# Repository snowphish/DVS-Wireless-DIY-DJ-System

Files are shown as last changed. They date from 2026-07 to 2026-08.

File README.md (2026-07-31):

# Wireless DIY DVS

## Lineage and AI authorship disclosure

This is my own spin on the original project from
[FelipeAlme/DVS-Wireless-DIY-DJ-System](https://github.com/FelipeAlme/DVS-Wireless-DIY-DJ-System),
which established the original transmitter and receiver system. This fork
includes some added functionality like unified receiver control, spin
calibration, automatic pairing, failover, telemetry, the Windows Manager, and
web flashing.

**All programming in this fork has been done by AI.** The project owner has
provided the requirements, hardware design decisions, physical builds, testing,
diagnosis feedback, and final approval, while AI systems generated and modified
the firmware, desktop application, web flasher, build tooling, and documentation.

Wireless DIY DVS turns two ordinary turntables into a two-deck digital vinyl
control system without needles or timecode records. Battery-powered ESP32-C3
gyro pucks measure platter movement over ESP-NOW, while one ESP32-S3 receiver
generates line-level Serato CV02 timecode or a Traktor-compatible quadrature
carrier signal for both decks.

> **[Flash the receiver and pucks in Chrome or Edge](https://snowphish.github.io/DVS-Wireless-DIY-DJ-System/)**

The package also includes a self-contained Windows x64 manager for monitoring,
pairing, calibration, deck swapping, and receiver settings over USB.

## System overview

```text
Turntable 1 + gyro puck --\                         /--> DAC A --> audio interface
                            ESP-NOW --> S3 receiver
Turntable 2 + gyro puck --/                         \--> DAC B --> audio interface
                                         |
                                         +--> USB --> DVS Manager for Windows
```

One receiver handles both decks. Both pucks run the same firmware for their
sensor type; deck 1 and deck 2 are assigned automatically during pairing and
can be swapped later from DVS Manager.

## Highlights

- Full Serato CV02 output and carrier-only Traktor output from one unified
  receiver build.
- Two simultaneous decks over low-latency ESP-NOW on channel 11.
- MPU6050 and BMI160/BMI120 transmitter variants.
- Automatic MAC-based pairing and reconnect to the puck's previous deck.
- One-time platter-speed calibration stored independently by each puck.
- Hold-last-stable-RPM failover if a wireless link drops.
- Live battery voltage, RPM, 7-second signal/loss averages, and packet age.
- USB configuration with automatic COM-port discovery and reconnection.
- Adjustable output gain, base speed, LED brightness, battery threshold, and
  pairing window, including an option to suppress low-battery LED flashing.
- Browser-based flashing with no Arduino installation required.

## Quick start

1. Open the **[web flasher](https://snowphish.github.io/DVS-Wireless-DIY-DJ-System/)**
   in desktop Chrome or Edge.
2. Flash **Unified receiver** to the ESP32-S3 receiver.
3. Flash the transmitter build matching each puck's gyro:
   - `MPU6050` for MPU6050 pucks.
   - `BMI160 / BMI120` for either Bosch chip ID `0xD1` or `0xD3`.
4. Power the receiver first, then switch on the two pucks one at a time. The
   first new puck becomes deck 1 and the second becomes deck 2.
5. Connect the receiver's native USB data port to Windows and run
   [`Windows_Manager/DVSManager.exe`](Windows_Manager/DVSManager.exe).
6. Select Serato CV02 or Traktor carrier in **Settings**, choose the platter
   speed in **Quick controls**, and calibrate with the platters settled at 0%
   pitch.
7. Connect both PCM5102A outputs to the audio interface's **line inputs**, set
   up the corresponding input mode in the DJ software, and use **Relative
   mode**.

### Important Traktor limitation

The current Traktor mode outputs only the bare quadrature carrier used for
speed and direction tracking. It does **not** generate the complete Traktor
Scratch MK2 position/authenticity bitstream, so Traktor will not detect it as
genuine timecode for now.

Use **Relative mode** and disable Traktor's timecode error messages/warnings.
With those errors disabled, Traktor can follow platter speed and direction from
the carrier, but genuine-timecode detection and absolute position are not
available. Serato mode is unaffected and continues to output full CV02
timecode.

The Windows executable is not code-signed, so SmartScreen may show an
unrecognized-app warning. Verify it against [`SHA256SUMS.txt`](SHA256SUMS.txt)
before choosing **More info > Run anyway**.

## Pairing and deck assignment

- The receiver opens its pairing window at boot.
- The first unassigned puck becomes deck 1; the second becomes deck 2.
- A previously paired puck that reconnects reclaims its own deck.
- **Open pairing** in DVS Manager allows a new puck to claim a free deck.
- **Swap decks** exchanges the two assignments without reflashing either puck.
- Holding the receiver's GPIO 4 pairing button for about 1.5 seconds clears
  both assignments and reopens pairing.

## Calibration

Power each puck on while its platter is stopped so boot-time gyro zeroing is
valid. For the one-time speed calibration:

1. Set both turntables to 33 1/3 or 45 RPM with pitch at exactly 0%.
2. Let the platters settle completely.
3. Select the same base speed under **Quick controls**.
4. Click **Calibrate pucks at selected speed**.
5. Do not touch either platter during the roughly 10-second sample.

The learned gyro scale is saved in each puck. Normal power-on zeroing still
happens every time because gyro bias changes with temperature.

## DVS Manager

`DVSManager.exe` is a portable, self-contained .NET 8 application for 64-bit
Windows. No installer or separate .NET runtime is required. It automatically
finds the receiver, reconnects after USB resets or COM-number changes, and
keeps receiver settings in the receiver's NVS rather than on the PC.

Closing the window sends it to the system tray. System balloon notifications
are intentionally disabled so disconnects do not produce notification sounds;
status changes remain visible in the app's Activity view.

If a deck enters **HOLDING**, switch that deck to Internal mode, restore the
puck connection, wait for live RPM to return, then switch back to Relative.

## Repository layout

| Path | Contents |
|---|---|
| [`Firmware/receiver_s3_unified_revised`](Firmware/receiver_s3_unified_revised) | ESP32-S3 two-deck receiver firmware |
| [`Firmware/transmitter_c3_mpu6050_revised`](Firmware/transmitter_c3_mpu6050_revised) | ESP32-C3 MPU6050 puck firmware |
| [`Firmware/transmitter_bmi160_revised`](Firmware/transmitter_bmi160_revised) | ESP32-C3 BMI160/BMI120 puck firmware |
| [`Windows_Manager`](Windows_Manager) | Ready-to-run Windows Manager and USB protocol |
| [`Source/DVSManager`](Source/DVSManager) | Complete .NET 8 WPF source |
| [`docs`](docs) | GitHub Pages web flasher, manifests, and merged binaries |
| [`Old`](Old) | Printable enclosure files, Fusion 360 sources, and original build photos |
| [`licenses`](licenses) | Included third-party license notices |

## CAD cases and original build photos

[`Old/`](Old) preserves the original non-custom-PCB enclosure
designs and build photos. It includes print-ready `.3mf` receiver, transmitter,
and carry-box parts plus the editable Fusion 360 `.f3d` sources. Read the
folder's assembly notes before printing or modifying the designs.

## Firmware build settings

The checked-in web-flasher images were built with Arduino CLI 1.5.1, ESP32
Arduino core 3.3.10, a 4 MB default partition layout, and Adafruit NeoPixel
1.15.5 for the receiver.

| Firmware | Board/options |
|---|---|
| Receiver | `ESP32S3 Dev Module`, Hardware CDC/JTAG, USB CDC on boot, PSRAM disabled |
| Transmitters | `ESP32C3 Dev Module`, USB CDC on boot |

All receiver and transmitter builds must use ESP-NOW channel 11 and protocol
version 1. If either is changed, every board must be rebuilt together.

## Important electrical notes

- PCM5102A output is line level and can be much hotter than a phono cartridge.
  Use line inputs or suitable attenuation; do not feed an unattenuated output
  into a phono preamp.
- The puck battery monitor expects a 2:1 divider: switched BAT+ through 100k to
  GPIO 3, then 100k to ground, with 100 nF from GPIO 3 to ground.
- Current transmitter I2C pins are SDA GPIO 8 and SCL GPIO 9.
- The receiver DAC pins and hardware assumptions are documented at the top of
  the receiver sketch; confirm them against your board before powering it.

Bench-test direction, stop stability, calibration, both DAC outputs, link-loss
recovery, battery readings, and the selected Serato/Traktor mode before live use.

## Trademarks

Serato and Traktor are trademarks of their respective owners. This project is
not affiliated with or endorsed by Serato or Native Instruments.

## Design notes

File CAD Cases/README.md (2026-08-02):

# DIY DVS cases, schematics, and BOM

This folder contains the printable enclosure files and a hardware bill of
materials for a complete two-deck system:

- two wireless transmitter pucks (TX);
- one dual-deck receiver (RX); and
- one optional storage case.

The matching manufacturing archives are
[`../PCB/TX-gerber.rar`](../PCB/TX-gerber.rar) and
[`../PCB/RX-Gerber.rar`](../PCB/RX-Gerber.rar).

## Printable files

| File | Quantity to print | Purpose |
|---|---:|---|
| `TX-Bottom.stl` | 2 | Transmitter puck base |
| `TX-Top.stl` | 2 | Transmitter puck lid |
| `RX-bottom.stl` | 1 | Receiver base |
| `RX-top.3mf` | 1 | Receiver lid |
| `RX-button.stl` | 2 | Receiver button cap |
| `storage-bottom.stl` | 1 optional | Storage/carry case base |
| `storage-top.stl` | 1 optional | Storage/carry case lid |

Check the slicer preview before printing. The CAD files do not prescribe a
specific material, layer height, wall count, or support strategy, so choose
settings appropriate to your printer and expected use.

## Complete BOM: two TX and one RX

### PCB and electronic assemblies

| Quantity | Component | Used by | Notes |
|---:|---|---|---|
| 2 | TX PCB | TX | Order from `TX-gerber.rar` |
| 1 | RX PCB | RX | Order from `RX-Gerber.rar` |
| 2 | ESP32-C3 SuperMini, through-hole module | TX | One per puck; flash the BMI160/BMI120 TX firmware |
| 2 | GY-BMI160 breakout module | TX | A compatible BMI120 may work with the same firmware |
| 2 | EG1213 slide switch | TX | PCB footprint `EG1213` |
| 4 | 100 kOhm resistor, 1%, 0603 | TX | R1 and R2 on each TX PCB |
| 2 | 100 nF ceramic capacitor, 0603 | TX | C1 on each TX PCB |
| 2 | Protected rechargeable 16340 Li-ion cell | TX | CR123A size; the case is intended for a removable cell |
| 2 sets | 12 mm x 12 mm battery contacts | TX | One positive/negative contact set per puck |
| 1 | ESP32-S3-DevKitC-1 N16R8 | RX | Current firmware uses the onboard WS2812 on GPIO 48 |
| 2 | PCM5102A stereo I2S DAC breakout | RX | One DAC per deck; use modules matching the PCB footprint |
| 2 | 6 mm through-hole momentary pushbutton, 5 mm high | RX | PCB footprint `SW_PUSH_6mm_H5mm` |

### Mechanical and wiring items

| Quantity | Item | Notes |
|---:|---|---|
| 2 sets | Printed TX base and lid | One set per turntable |
| 1 set | Printed RX base and lid | Receiver enclosure |
| 2 | Printed RX button cap | One per receiver button |
| As needed | M2 x 4 mm self-tapping screws | Secure the TX PCBs in the transmitter cases |
| As needed | M3 x 4 mm self-tapping screws | Secure the RX PCB in the receiver case |
| 4 | 20 x 20 mm self-adhesive pads | Fit two underneath each transmitter |
| As needed | 26-30 AWG insulated hookup wire | Use multiple colors for power, ground, and signals |
| As needed | Heat-shrink tubing | Insulate exposed wiring and provide strain relief |
| As needed | Hot glue or electronics-safe adhesive | Secure wiring without covering USB ports or buttons |

### Cables and external equipment

| Quantity | Item | Notes |
|---:|---|---|
| 1 | USB-C data cable | Receiver-to-Windows USB connection and power |
| 2 | Stereo audio cables or adapters | One deck per PCM5102A output |
| 1 | Audio interface | Must provide suitable line-level inputs for both decks |
| 2 | Turntables | One transmitter puck per platter |
| 1 | Windows PC | Runs the DJ software and optional DVS Manager |

Buy at least one spare ESP32-C3, BMI160, and PCM5102A module. Small passives
are normally sold in strips or kits, so ordering extras is inexpensive.

## TX population values

The current KiCad schematic displays generic `R_US` and `C` labels. Populate
the PCB using these firmware-required values:

```text
Switched BAT+ ---- R1 100k ----+---- GPIO 3
                               |
                             C1 100 nF
                               |
GPIO 3 ---------- R2 100k ----+---- GND
```

The two 100 kOhm resistors form a 2:1 battery-voltage divider. C1 filters the
ADC input. The divider must be connected to switched battery power so it does
not continuously drain the cell while the puck is off.

The BMI160 connections used by the current firmware are:

| BMI160 signal | ESP32-C3 pin |
|---|---|
| SDA | GPIO 8 |
| SCL | GPIO 9 |
| INT1 | GPIO 4 |
| CS | 3.3 V |
| SA0 | GND |

Flash each transmitter with the BMI160/BMI120 firmware. Power on a puck only
while its platter is stationary so boot-time gyro zeroing can complete
correctly.

## RX connections

| Signal | Deck A DAC | Deck B DAC |
|---|---:|---:|
| BCK | GPIO 2 | GPIO 14 |
| LRCK / WS | GPIO 1 | GPIO 13 |
| DATA / DIN | GPIO 42 | GPIO 12 |

The receiver buttons connect GPIO 4 and GPIO 5 to ground. The firmware enables
the ESP32-S3 internal pull-ups.

## Schematics

### Receiver

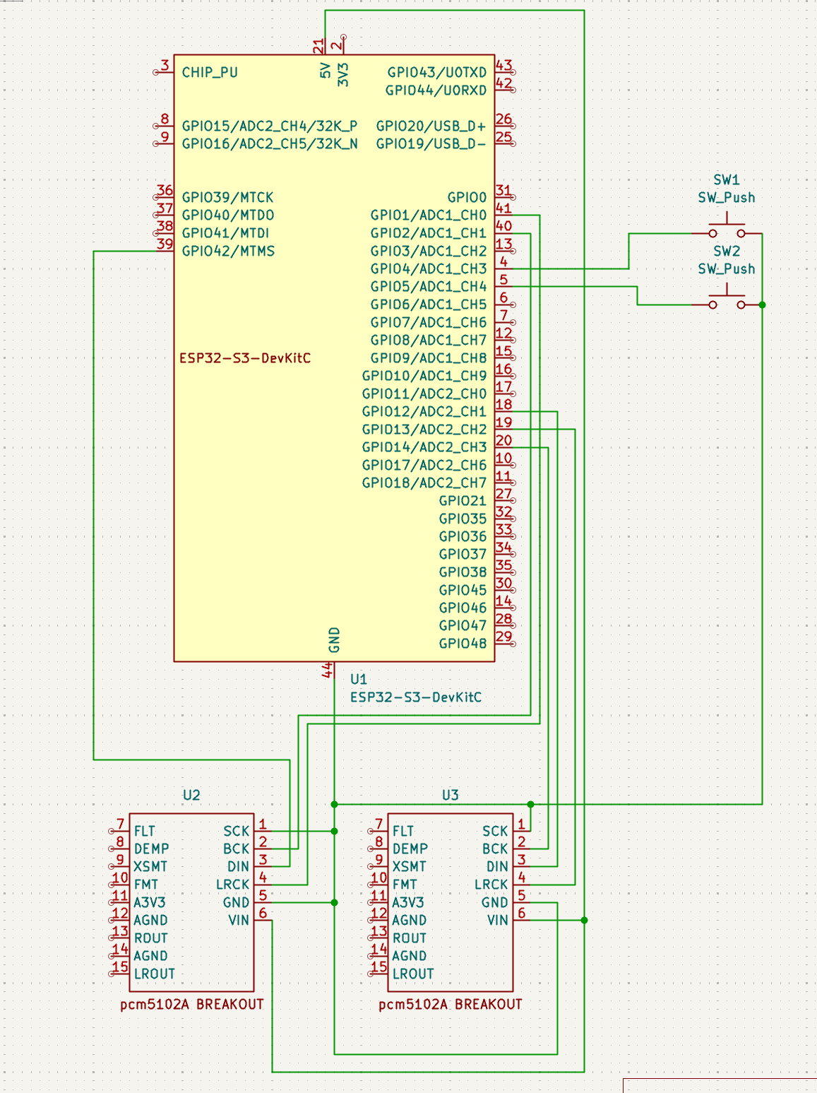
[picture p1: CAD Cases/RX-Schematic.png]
DIY DVS receiver schematic


### Transmitter

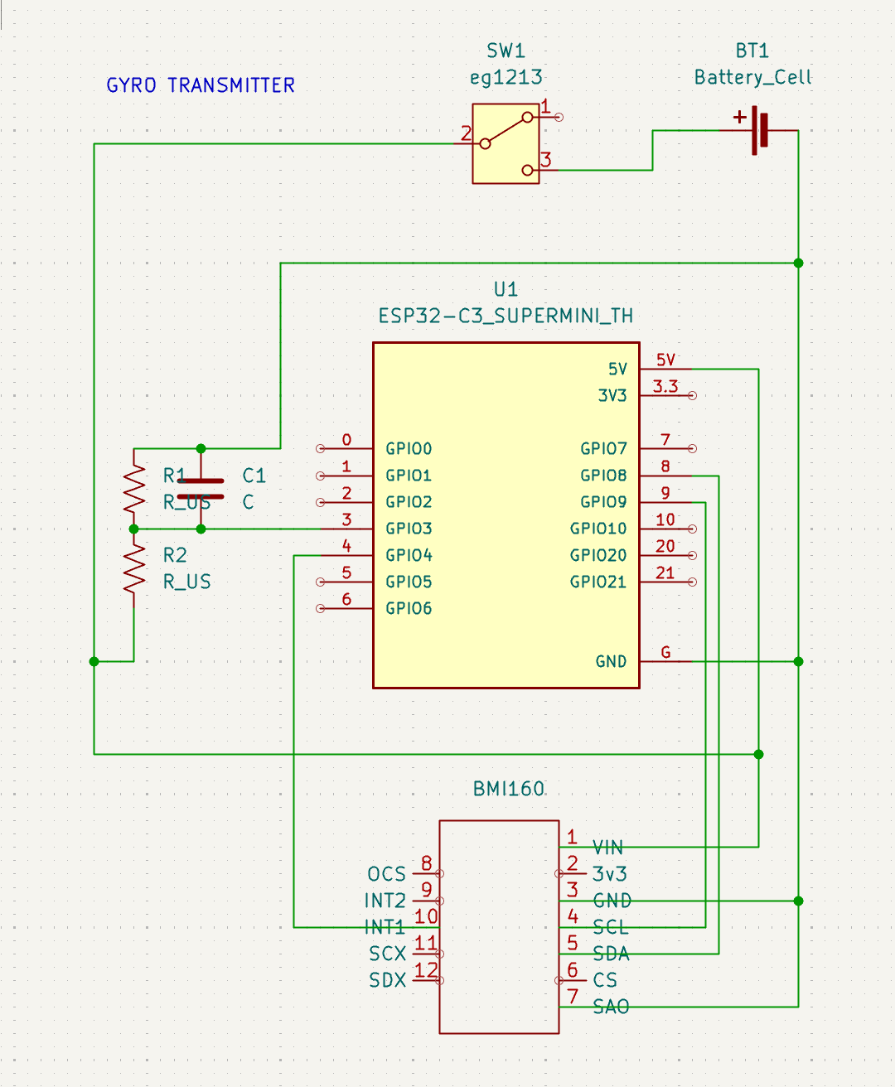
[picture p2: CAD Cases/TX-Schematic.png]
DIY DVS BMI160 transmitter schematic


## Safety and first-power checks

- Verify battery polarity and check for a short between power and ground
  before inserting a cell.
- Use protected Li-ion cells and a charger intended for the exact cell type.
  Do not charge an improvised or damaged battery assembly.
- Test each transmitter and the receiver on the bench before installing them
  in their cases.
- PCM5102A output is line level and can be much hotter than a phono cartridge.
  Connect it to line inputs or suitable attenuation, not directly to an
  unattenuated phono preamp.
- Verify both deck directions, stopped-platter stability, battery readings,
  calibration, and both DAC outputs before performance use.

## Assembled case previews

Completed receiver, transmitter, and storage cases:

Assembled DIY DVS receiver, transmitter, and storage cases

Internal view of two transmitter pucks and the dual-deck receiver:

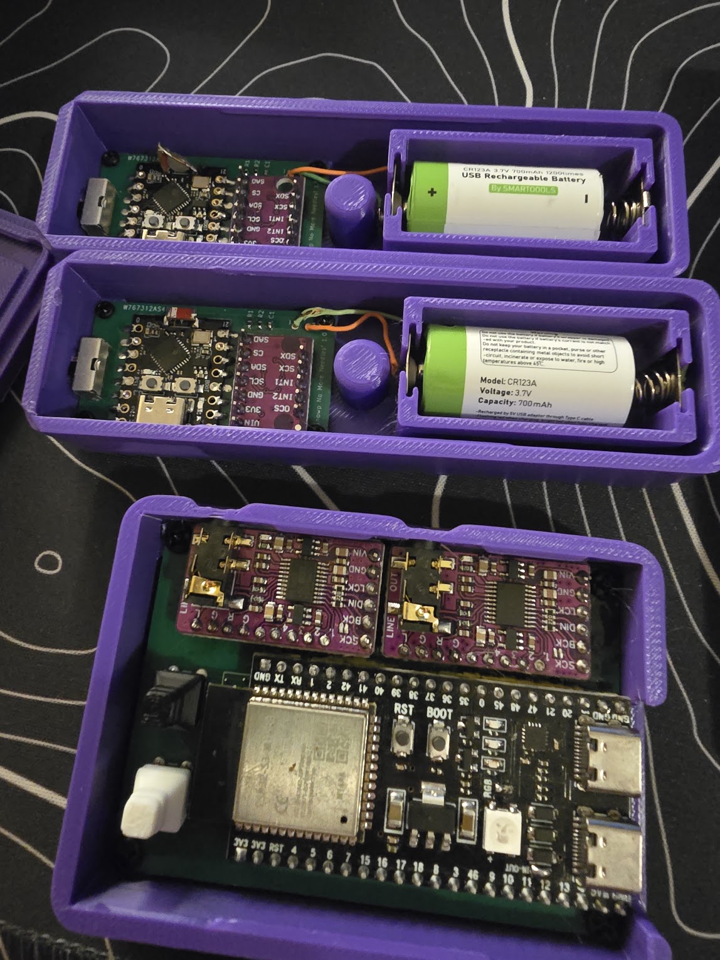
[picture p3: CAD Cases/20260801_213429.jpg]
Internal view of the assembled DIY DVS transmitters and receiver


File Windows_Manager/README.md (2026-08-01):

# DVS Manager for Windows

DVS Manager is the always-on USB control application for the DIY wireless DVS
receiver. It replaces the Wi-Fi access-point portal for normal use while
leaving the receiver fully standalone.

## What it does

- Finds the ESP32-S3 receiver automatically on any COM port.
- Reconnects after receiver resets, USB removal, or COM-port number changes.
- Shows both deck links, battery gauges, RPM, 7-second RSSI/loss averages,
  packet age, pairing state, and calibration messages.
- Edits timecode format, output gain, base speed, LED brightness, pairing
  window, low-battery threshold, low-battery LED flashing, and both physical
  receiver-button actions.
- Starts speed-specific calibration, opens pairing, or swaps deck assignments
  over USB.
- Records link, battery, pairing, and calibration events in the in-app Activity
  view. System balloon notifications are suppressed to prevent alert sounds.
- Can run in the system tray and start minimized with Windows. The X button
  exits by default; optional **Exit to tray** behavior is available in Settings.
- Exports the current session's activity log as CSV.

Settings remain in the receiver's NVS. Closing the app does not stop timecode
or change failover behavior.

## First use

1. Flash `receiver_s3_unified_revised.ino` from the companion firmware package,
   or use the repository's browser-based web flasher.
2. In Arduino IDE, select the ESP32-S3 receiver board and enable **USB CDC On
   Boot** so Windows exposes a COM port.
3. Connect the receiver to the PC with its native USB data cable.
4. Run `DVSManager.exe`. No installer or .NET download is required.
5. Allow several seconds for automatic detection after a fresh receiver boot.

The executable is not code-signed. Windows SmartScreen may show an
unrecognized-app warning on first launch; use **More info → Run anyway** only
if the file came from this package and its SHA-256 matches `SHA256SUMS.txt`.

## Normal operation

Closing the window exits DVS Manager by default. Enable **Exit to tray** in
Settings to keep monitoring after the X button is clicked; use the tray menu
to exit completely.

If a puck link is lost, the receiver keeps its intentional hold-last-stable-RPM
behavior. DVS Manager displays **HOLDING** and notifies you to:

1. Switch that deck to Internal.
2. Reconnect or power-cycle the puck.
3. Wait for the manager to report that the link is restored.
4. Return the deck to Relative.

## Emergency AP

The old web portal is retained as an optional recovery path. It is never needed
for routine management. The portal is available whenever either receiver
button is assigned the **Enable / disable AP** action.

## Source build

The included source targets .NET 8 WPF on Windows x64.

```powershell
dotnet build DVSManager.csproj -c Release
dotnet publish DVSManager.csproj -c Release -r win-x64 --self-contained true `
  -p:PublishSingleFile=true -p:IncludeNativeLibrariesForSelfExtract=true
```

`lib/System.IO.Ports.dll` is the Windows assembly from Microsoft's
`System.IO.Ports` 8.0.0 NuGet package.

## Safety

Bench-test USB detection, both deck directions, calibration, pairing, battery
warnings, link loss/recovery, Serato, and Traktor before performance use. The
application builds without warnings and its protocol parser passes the included
self-test. The unified receiver and both transmitter variants compile with
ESP32 Arduino core 3.3.10; USB, radio, and audio behavior must still be verified
with the physical hardware before performance use.

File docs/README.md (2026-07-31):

# DVS web flasher

This directory is published by GitHub Pages at:

<https://snowphish.github.io/DVS-Wireless-DIY-DJ-System/>

It uses ESP Web Tools to flash three complete merged images at offset `0x0`:

- Unified ESP32-S3 receiver
- ESP32-C3 transmitter with MPU6050
- ESP32-C3 transmitter with BMI160 or BMI120

The binaries are compiled from the matching sketches under `Firmware/` with
ESP32 Arduino core 3.3.10. The JSON manifests select the correct chip family and
must remain next to `index.html`; binary paths are relative to this directory.

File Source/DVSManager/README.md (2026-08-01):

# DVS Manager for Windows

DVS Manager is the always-on USB control application for the DIY wireless DVS
receiver. It replaces the Wi-Fi access-point portal for normal use while
leaving the receiver fully standalone.

## What it does

- Finds the ESP32-S3 receiver automatically on any COM port.
- Reconnects after receiver resets, USB removal, or COM-port number changes.
- Shows both deck links, battery gauges, RPM, RSSI, packet loss, packet age,
  pairing state, and calibration messages.
- Edits timecode format, output gain, base speed, LED brightness, pairing
  window, low-battery threshold, low-battery LED flashing, and both physical
  receiver-button actions.
- Starts calibration, opens pairing, or clears assignments over USB.
- Sends Windows notifications for low/critical battery, link loss, link
  recovery, and completed calibration.
- Can run in the system tray and start minimized with Windows. The X button
  exits by default; optional **Exit to tray** behavior is available in Settings.
- Exports the current session's activity log as CSV.

Settings remain in the receiver's NVS. Closing the app does not stop timecode
or change failover behavior.

## First use

1. Flash `receiver_s3_unified_revised.ino` from the companion firmware package.
2. In Arduino IDE, select the ESP32-S3 receiver board and enable **USB CDC On
   Boot** so Windows exposes a COM port.
3. Connect the receiver to the PC with its native USB data cable.
4. Run `DVSManager.exe`. No installer or .NET download is required.
5. Allow several seconds for automatic detection after a fresh receiver boot.

The executable is not code-signed. Windows SmartScreen may show an
unrecognized-app warning on first launch; use **More info → Run anyway** only
if the file came from this package and its SHA-256 matches `SHA256SUMS.txt`.

## Normal operation

Closing the window exits DVS Manager by default. Enable **Exit to tray** in
Settings to keep monitoring after the X button is clicked; use the tray menu
to exit completely.

If a puck link is lost, the receiver keeps its intentional hold-last-stable-RPM
behavior. DVS Manager displays **HOLDING** and notifies you to:

1. Switch that deck to Internal.
2. Reconnect or power-cycle the puck.
3. Wait for the manager to report that the link is restored.
4. Return the deck to Relative.

## Emergency AP

The old web portal is retained as an optional recovery path. It is never needed
for routine management. The portal is available whenever either receiver
button is assigned the **Enable / disable AP** action.

## Source build

The included source targets .NET 8 WPF on Windows x64.

```powershell
dotnet build DVSManager.csproj -c Release
dotnet publish DVSManager.csproj -c Release -r win-x64 --self-contained true `
  -p:PublishSingleFile=true -p:IncludeNativeLibrariesForSelfExtract=true
```

`lib/System.IO.Ports.dll` is the Windows assembly from Microsoft's
`System.IO.Ports` 8.0.0 NuGet package.

## Safety

Bench-test USB detection, both deck directions, calibration, pairing, battery
warnings, link loss/recovery, Serato, and Traktor before performance use. The
application builds without warnings and its protocol parser passes the included
self-test. The receiver firmware passed delimiter, preprocessor, embedded-page,
and JavaScript validation; the final Arduino compile and USB/radio/audio
behavior must still be verified with the physical receiver and its known-good
board settings.

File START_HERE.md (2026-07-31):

# DIY DVS complete package

This package contains the two-deck ESP-NOW DVS firmware plus the new Windows
DVS Manager. The manager uses the receiver's existing USB connection, so normal
configuration and monitoring no longer require Wi-Fi AP mode.

## Package contents

| Folder | Purpose |
|---|---|
| `Windows_Manager` | Self-contained Windows x64 application and USB protocol |
| `Firmware/receiver_s3_unified_revised` | ESP32-S3 receiver with USB Manager support |
| `Firmware/transmitter_bmi160_revised` | ESP32-C3 puck with Bosch BMI160 |
| `Firmware/transmitter_c3_mpu6050_revised` | ESP32-C3 puck with MPU6050 |
| `Source/DVSManager` | Complete .NET 8 WPF application source |
| `docs` | GitHub Pages web flasher, manifests, compiled images, and revision notes |

Use only the transmitter sketch matching the IMU fitted to that puck.

## Recommended setup order

1. Use the web flasher linked from `README.md`, or flash
   `receiver_s3_unified_revised.ino` in Arduino IDE.
2. Flash the BMI160/BMI120 or MPU6050 build to each matching puck.
3. Power the receiver first, then the pucks one at a time.
4. Connect the receiver's native USB data port to the Windows PC.
5. Run `Windows_Manager/DVSManager.exe`.
6. Calibrate both pucks from the manager after the platters settle at the
   selected speed and 0% pitch.

## Receiver Arduino settings

- Board: `ESP32S3 Dev Module`, adjusted for the exact S3 module and flash size.
- ESP32 Arduino core: a recent 3.x release.
- **USB CDC On Boot: Enabled** so the receiver appears as a Windows COM port.
- USB MIDI remains disabled in this production receiver.
- Library: `Adafruit NeoPixel`.

Retain the known-good partition, flash, PSRAM, and upload settings for the
physical receiver board.

## Transmitter Arduino settings

- Board: `ESP32C3 Dev Module`, adjusted for the exact puck board.
- ESP32 Arduino core: the same recent 3.x release used by the receiver.
- Power each puck with its platter stopped so gyro-zero calibration is valid.

The receiver and transmitters must all retain ESP-NOW channel `11` and radio
protocol version `1`.

## DVS Manager

`DVSManager.exe` is self-contained for 64-bit Windows. It does not require an
installer or a separate .NET runtime.

The app automatically:

- Finds the receiver on a COM port.
- Reconnects after USB removal, board resets, or COM-number changes.
- Shows both battery gauges and live radio/link diagnostics.
- Stores settings directly in receiver NVS.
- Runs in the system tray and optionally starts with Windows.
- Notifies on link loss/restoration and low/critical battery.

The executable is not code-signed, so Windows SmartScreen may display an
unrecognized-app warning on first launch. Verify `SHA256SUMS.txt` before using
**More info → Run anyway**.

## Intentional failover behavior

Link loss continues to hold the last stable RPM indefinitely. When DVS Manager
shows **HOLDING**:

1. Switch the affected deck to Internal.
2. Reconnect the puck.
3. Wait for **link restored**.
4. Return the deck to Relative.

## Emergency AP

The original web portal remains an optional recovery path. DVS Manager can
disable the receiver button's AP fallback entirely. AP mode is never needed for
normal Windows management.

## Calibration

1. Select 33⅓ or 45 RPM in DVS Manager.
2. Set both turntables to that speed and pitch to exactly 0%.
3. Wait for both platters to settle fully.
4. Press **Calibrate** and confirm.
5. Do not touch the platters during the approximately 10-second sampling period.

Each puck stores its learned gyro trim independently.

## Electrical warning

PCM5102A output can be much hotter than a phono cartridge. Use the intended
line-level input or suitable attenuation. Do not feed an unattenuated DAC
output into a phono preamp unless the hardware was designed for it.

## Before performance use

- Verify forward/reverse direction and stopped-platter stability on both decks.
- Verify Serato and Traktor at conservative gain first.
- Test USB unplug/reconnect and manager auto-reconnection.
- Test intentional failover and the Internal → reconnect → Relative workflow.
- Test low-battery indication, pairing reset, and calibration.
- Keep the emergency AP enabled until the USB workflow has been bench-tested.

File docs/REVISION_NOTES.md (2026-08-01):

# DIY DVS revision notes — USB Manager release

## Receiver button mapping - 2026-08-01

- Receiver firmware advanced to 1.2.6.
- White button 1 and black button 2 can be mapped independently in Manager
  Settings to toggle the AP, swap decks, open pairing, or start spin
  calibration at the selected base speed.
- Button mappings persist in receiver NVS and require a 1.5-second hold.
- Either physical button can also be disabled so holding it has no effect.
- Removed the redundant Emergency AP availability toggle; assigning the AP
  action to either button now always enables that action.

## Receiver LED setting and Manager window update - 2026-07-31

- Receiver firmware advanced to 1.2.4.
- Added an NVS-backed option to enable or suppress the repeating low-battery
  receiver LED pulse alert without disabling battery telemetry or events.
- Added the LED-alert toggle to DVS Manager Settings and the USB protocol as
  the backward-compatible optional `lbled` setting.
- Made the full non-button area of the Manager's top bar draggable.

## Web flasher and distribution refresh - 2026-07-31

- Restored the GitHub Pages ESP Web Tools flasher for the current three-build
  firmware layout: unified receiver, MPU6050 puck, and BMI160/BMI120 puck.
- Recompiled all three merged flash images with Arduino CLI 1.5.1, ESP32
  Arduino core 3.3.10, and Adafruit NeoPixel 1.15.5.
- Receiver build uses ESP32-S3 hardware CDC with USB CDC on boot; transmitter
  builds use ESP32-C3 with USB CDC on boot.
- Espressif image inspection confirmed valid chip IDs, checksums, and validation
  hashes for all three application images.
- Added a complete repository landing-page README and removed the obsolete
  original Manager executable from the current release tree.

## Firmware audit fixes - 2026-07-23

- Receiver firmware version advanced to 1.2.1.
- Deck LIVE/HOLDING freshness now advances only on motion DATA packets.
  Battery, handshake, calibration and IMU-fault events can no longer interrupt
  hold-last-stable-RPM failover.
- Both transmitter variants enter reported IMU fault code 3 after 50
  consecutive gyro-read failures, including failures during boot zero-cal.
- BMI160 PMU startup failure is now fatal and reported instead of continuing
  with a suspended gyro.
- BMI160 INT1 uses a pull-down so an older puck without the interrupt wire
  deterministically enters the bounded free-running fallback.
- Stored-bias cross-check rejection has its own event code and reports delta
  dps instead of mislabeling the value as platter RPM.
- Legacy `gain=` behavior is retained. Optional `gains=` and `gaint=` keys can
  explicitly update the Serato and Traktor gains; both values are emitted in
  manager and portal config JSON for future clients.
- ESP-NOW packet layout, protocol version and channel are unchanged.
- Windows DVS Manager source and executable are unchanged.
- Non-compiling structural, protocol, portal-JavaScript and semantic checks
  passed. Arduino compilation was intentionally not run.

## Windows DVS Manager 1.0

- Native Windows x64 WPF application matching the approved dashboard preview.
- Automatic receiver discovery using a protocol handshake instead of a fixed
  COM-port number.
- Automatic recovery after receiver reboot, USB removal, and COM renumbering.
- System-tray operation, optional start with Windows, and clean explicit exit.
- Prominent 3.0–4.2 V battery gauges plus RPM, RSSI, packet loss, packet age,
  pairing state, calibration state, and receiver firmware information.
- USB controls for timecode format, gain, base RPM, LED brightness, pairing
  duration, low-battery threshold, calibration, pairing, assignment reset, and
  emergency AP availability.
- Windows notifications for holding/restored links, low/critical/recovered
  battery, and completed calibration.
- Session activity log with CSV export.
- Receiver remains the source of truth for settings; closing the manager has no
  effect on timecode generation or failover.
- Single-file, self-contained Windows x64 build.

## Receiver USB protocol

- Versioned protocol over ESP32-S3 USB CDC at 115200 baud.
- Outgoing machine messages use line-delimited JSON with an `@DVS ` prefix.
- Incoming commands use bounded key/value tokens and require no JSON library on
  the microcontroller.
- Fixed 320-byte RX buffer with overlength rejection.
- USB input work is capped per `loop()` iteration.
- Telemetry is emitted every 250 ms from `loop()`, never from ESP-NOW callbacks
  or audio tasks.
- Human debug lines may remain enabled; the manager ignores unprefixed lines.
- Command IDs provide request/reply correlation.
- Settings are range-checked atomically before NVS writes.
- Emergency AP availability is now NVS-backed and manager-controlled.
- Link, battery, calibration, and AP-disabled events feed desktop notifications.

## Existing transmitter and receiver hardening retained

- Non-blocking ESP-NOW reconnect on both transmitter variants.
- BMI160 write verification and MPU6050 identity/configuration checks.
- Immediate low/critical battery transition reporting.
- Independent pending control/event slots for simultaneous pucks.
- Rollover-safe pairing and calibration deadlines.
- Traktor output clipping protection.
- Responsive offline settings portal with battery meters.
- Intentional indefinite hold-last-stable-RPM failover.

## Validation performed

- DVS Manager Release build: zero warnings and zero errors.
- Self-contained Windows x64 publish: successful.
- Executable startup smoke test: successful.
- Embedded USB JSON parser self-test: successful.
- Receiver/transmitter delimiter and preprocessor balance: successful.
- Embedded portal JavaScript syntax: successful.
- Exact portal HTML extraction: successful.
- Unified receiver Arduino compile: successful.
- MPU6050 and BMI160/BMI120 transmitter Arduino compiles: successful.
- Web-flasher manifests, asset paths, JavaScript, and image headers: successful.

## Required bench test

1. Confirm USB CDC enumerates and DVS Manager detects the receiver.
2. Confirm config round-trips and persists across receiver reboot.
3. Confirm both pucks pair, report battery, and calibrate.
4. Confirm live RPM direction and audio output on both decks.
5. Interrupt each radio link and verify HOLDING plus restoration notifications.
6. Verify the DJ software's Internal → reconnect → Relative recovery workflow.
7. Verify AP fallback enabled and disabled behavior.
8. Test Serato and Traktor at conservative and intended output levels.

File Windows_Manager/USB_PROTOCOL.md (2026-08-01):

# DVS Manager USB protocol

## Transport

- ESP32-S3 USB CDC serial
- 115200 baud
- UTF-8 / ASCII-compatible text
- One message per line (`\n`; receiver also accepts `\r\n`)
- Protocol version: `1`

Human debug text may share the port. Machine messages are always prefixed with
`@DVS `, so clients must ignore every other line.

## Receiver to manager

The content after `@DVS ` is JSON.

```text
@DVS {"type":"hello","id":1,"protocol":1,"firmware":"1.2.1","device":"DVS Receiver","serial":"A1B2C3D4"}
@DVS {"type":"config","id":2,"gain":0.300,"gains":0.300,"gaint":0.550,"format":0,"brightness":40,"pairWindow":60,"baseRpm":33.3333,"batteryLow":3.50,"lowBatteryLedAlert":true,"apFallback":true,"button1Action":2,"button2Action":0}
@DVS {"type":"response","id":3,"ok":true,"message":"settings saved"}
```

Status telemetry is sent every 250 ms:

```json
{
  "type": "status",
  "id": 0,
  "uptime": 12000,
  "format": 0,
  "gain": 0.300,
  "pairOpen": false,
  "pairRemaining": 0,
  "portalActive": false,
  "decks": [
    {
      "deck": 1,
      "assigned": true,
      "state": "live",
      "rpm": 33.33,
      "loss": 0.4,
      "rssi": -56,
      "battery": 3.91,
      "lowBattery": false,
      "age": 8,
      "cal": "trim loaded: 0.99870",
      "mac": "AA:BB:CC:DD:EE:01"
    }
  ]
}
```

Deck state is `live`, `holding`, or `offline`. Unknown loss/RSSI values are
JSON `null`.

Asynchronous events include:

- `link_lost`
- `link_restored`
- `battery_low`
- `battery_critical`
- `battery_recovered`
- `calibration_complete`
- `zero_cal_blocked`
- `zero_cal_complete`
- `zero_bias_mismatch`
- `imu_fault`
- `drdy_fallback`
- `ap_disabled`
- `receiver_button`

## Manager to receiver

Commands use space-separated ASCII tokens to keep the microcontroller parser
fixed-size and dependency-free. Every command should include a positive `id`;
the receiver echoes it in the corresponding reply.

```text
@DVS HELLO id=1
@DVS GET_CONFIG id=2
@DVS GET_STATUS id=3
@DVS PING id=4
@DVS CALIBRATE id=5
@DVS PAIR seconds=60 id=6
@DVS REPAIR id=7
@DVS SWAP_DECKS id=8
@DVS SET_CONFIG gain=0.300 fmt=0 bri=40 pwin=60 base=33.3333 blow=3.50 lbled=1 ap=1 btn1=2 btn2=0 id=9
@DVS SET_CONFIG gain=0.300 gains=0.300 gaint=0.550 fmt=1 bri=40 pwin=60 base=33.3333 blow=3.50 lbled=0 ap=1 id=10
```

Ranges:

- `gain`: 0.05–0.60
- `fmt`: 0 Serato CV02, 1 Traktor carrier
- `bri`: 5–255
- `pwin`: 10–300 seconds
- `base`: 30–50; normalized to 33.3333 or 45
- `blow`: 3.0–4.0 volts
- `lbled`: 0 suppress low-battery LED pulses, 1 enable them
- `ap`: accepted for compatibility but ignored; AP availability is controlled
  by the physical-button mappings
- `btn1`, `btn2`: 0 settings AP, 1 swap decks, 2 open pairing, 3 spin
  calibration at the selected base speed, 4 disabled

Optional `gains` and `gaint` keys explicitly update the stored Serato and
Traktor gains, respectively, using the same range as `gain`.
`lbled`, `btn1`, and `btn2` are optional for backward compatibility; when
omitted, the receiver keeps its corresponding currently stored setting.

For backward compatibility, bare `gain` updates the format that is active
before `fmt` is applied. If either explicit `gains` or `gaint` is present,
the supplied explicit values take precedence and bare `gain` is ignored.
The receiver then activates `fmt` and loads that format's stored gain.

The receiver has a 320-byte fixed input buffer and rejects overlong commands.
`SWAP_DECKS` atomically exchanges two existing puck assignments and fails when
fewer than two pucks are paired.
USB parsing and telemetry run only from `loop()` with bounded work; neither the
ESP-NOW callback nor audio tasks perform serial I/O.

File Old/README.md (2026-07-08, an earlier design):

# CAD Cases

> **Lineage:** part of a build based on [FelipeAlme/DVS-Wireless-DIY-DJ-System](https://github.com/FelipeAlme/DVS-Wireless-DIY-DJ-System)
> by Felipe Alme, who started this project.

3D-printed enclosures for the receiver and the transmitter puck.

Fair warning: these designs are **rudimentary** — I'm not very experienced
in CAD — but they print fine and they've been working fine for me. Use,
remix, or redraw them entirely; the `.f3d` Fusion 360 sources are included
alongside the print-ready `.3mf` files. 

## Files

| File | What it is |
|---|---|
| `receiver.f3d` / `Receiver-case.3mf` / `receiver-lid.3mf` | Receiver box (ESP32-S3 + two PCM5102A DACs) and its lid |
| `transmitter.f3d` / `transmitter-case.3mf` / `transmitter-lid.3mf` | Platter puck (ESP32-C3 + MPU6050 + battery) and its lid |
| `pack-box.f3d` / `pack-box.3mf` / `pack-box-lid.3mf` | Carry/storage box and lid |

## Assembly notes

- Almost everything is held in place with **hot glue** — boards, wiring. Low-tech, but it damps rattles and survives platter duty. The receiver status LED hole I also filled with hot glue, works fine for me. 
- You will need battery springs for the integrated battery holder, you can get these on amazon/AliExpress, they're 12mmx12mm battery contacts. 
- The one exception is the **gyro (MPU6050), mounted with M2 self-tapping
  plastic screws**. That one shouldn't be glued: it's the sensor doing the
  measuring, so it wants a rigid, flat, non-creeping mount to the case.
- The puck runs on a CR123a shaped li-ion rechargeable battery with onboard USB-C port, take it out for recharging, put a spare one in. You can find these on AliExpress. 

## Photos

Receiver internals (ESP32-S3 dev board + the two DAC boards, dual USB-C at
the top edge) next to the printed lids:

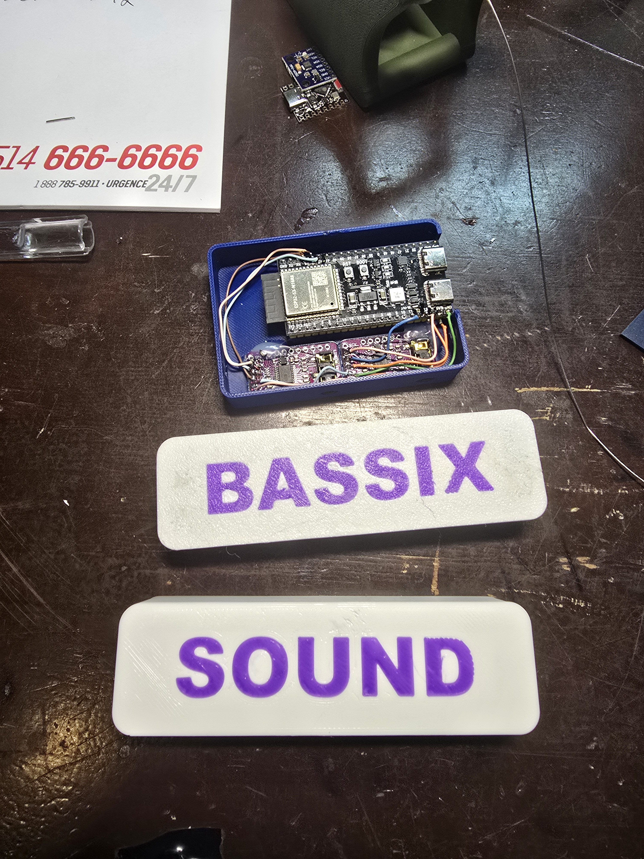
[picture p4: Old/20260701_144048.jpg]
Receiver internals and printed lids


Closed receiver (A/B deck outputs labeled, status LED lit) and the open
transmitter puck — battery bay up top, MPU6050 on its screws in the middle,
ESP32-C3 below:

Closed receiver and open transmitter puck

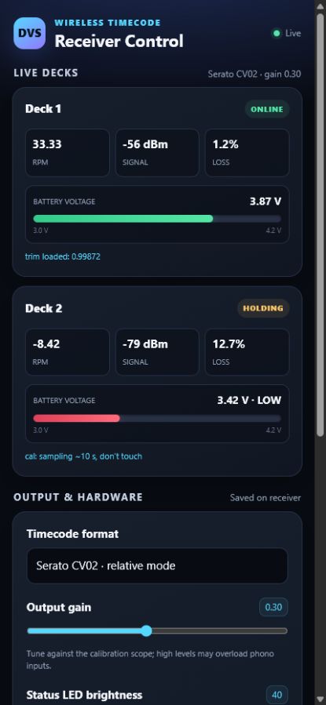
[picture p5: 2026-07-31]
docs/web_portal_preview.jpg

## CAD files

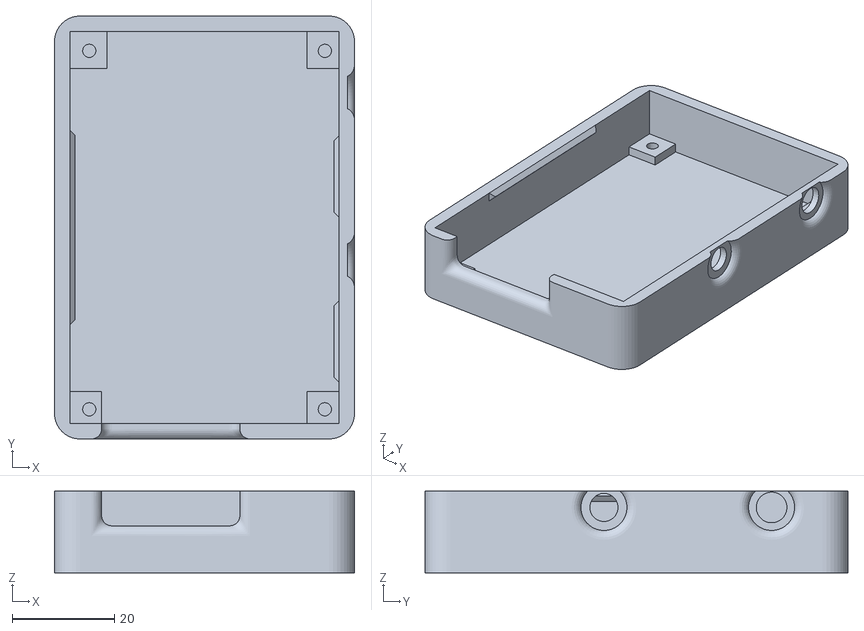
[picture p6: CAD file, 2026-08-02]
CAD Cases/RX-bottom.stl
58.6 x 82.6 x 16.0

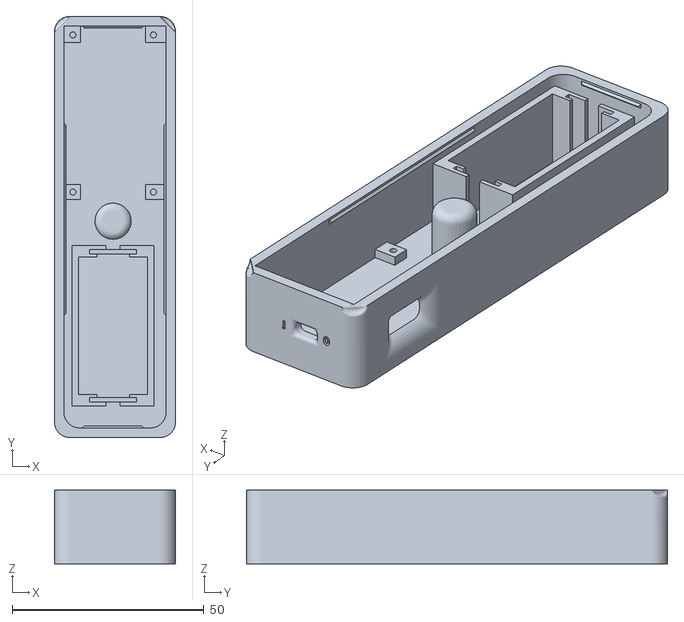
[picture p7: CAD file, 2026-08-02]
CAD Cases/TX-Bottom.stl
31.6 x 109.8 x 19.3

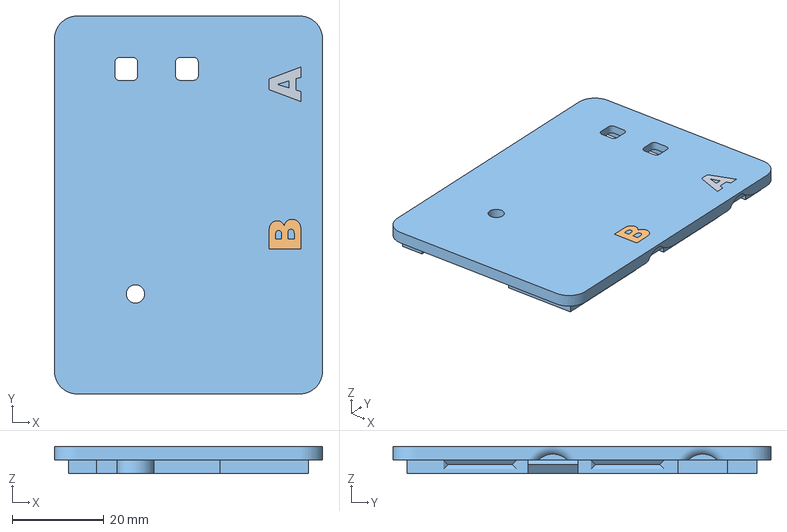
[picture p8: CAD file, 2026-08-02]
CAD Cases/RX-top.3mf
58.6 x 82.6 x 6.00 mm
A
B
top

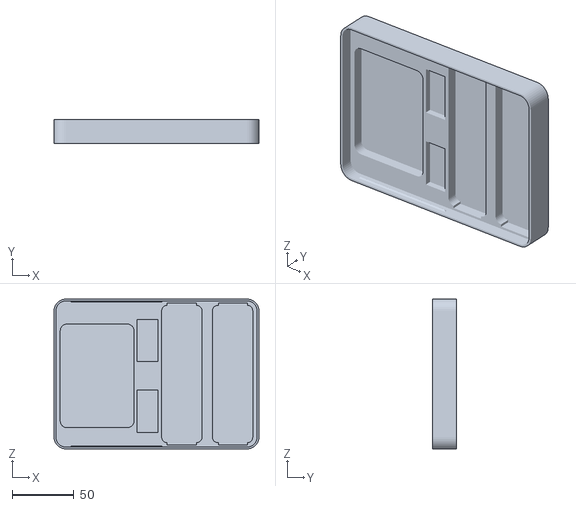
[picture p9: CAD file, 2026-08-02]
CAD Cases/storage-top.stl
165.3 x 19.5 x 120.8

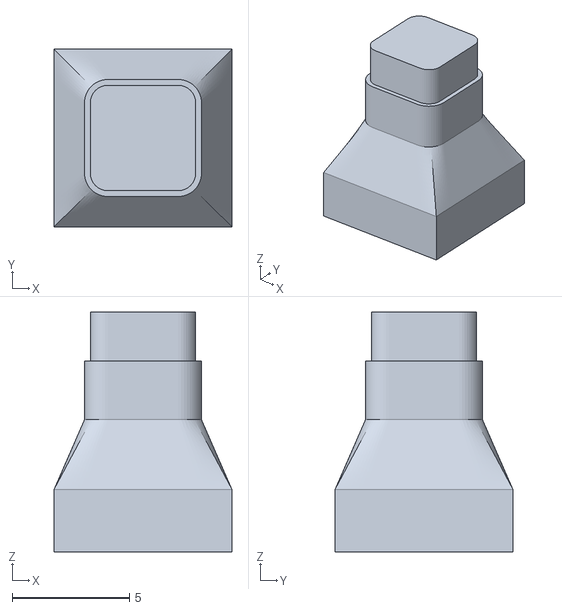
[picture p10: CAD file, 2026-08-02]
CAD Cases/RX-button.stl
7.60 x 7.60 x 10.3

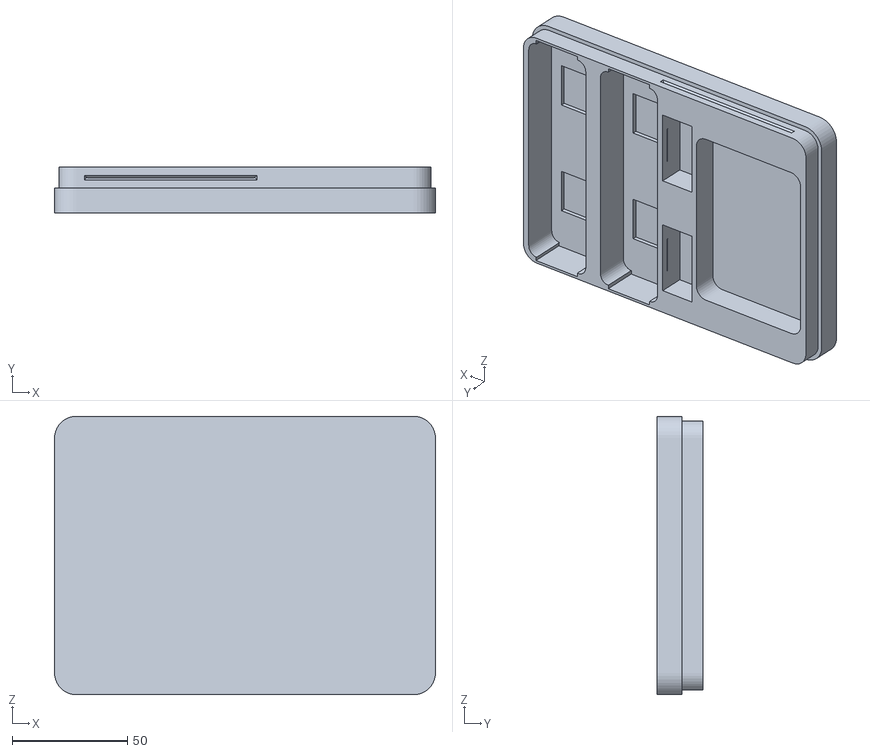
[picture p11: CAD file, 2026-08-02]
CAD Cases/storage-bottom.stl
165.3 x 19.8 x 120.8

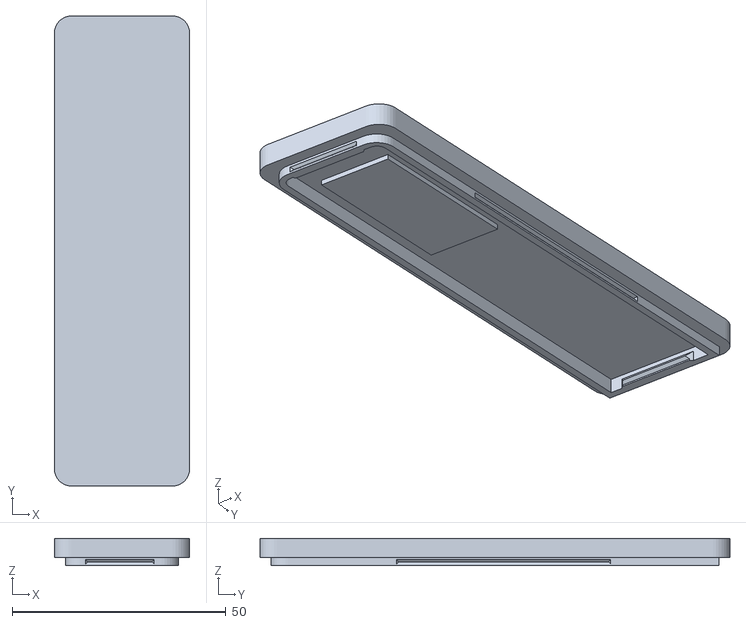
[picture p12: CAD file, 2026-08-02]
CAD Cases/TX-Top.stl
31.6 x 109.8 x 6.40

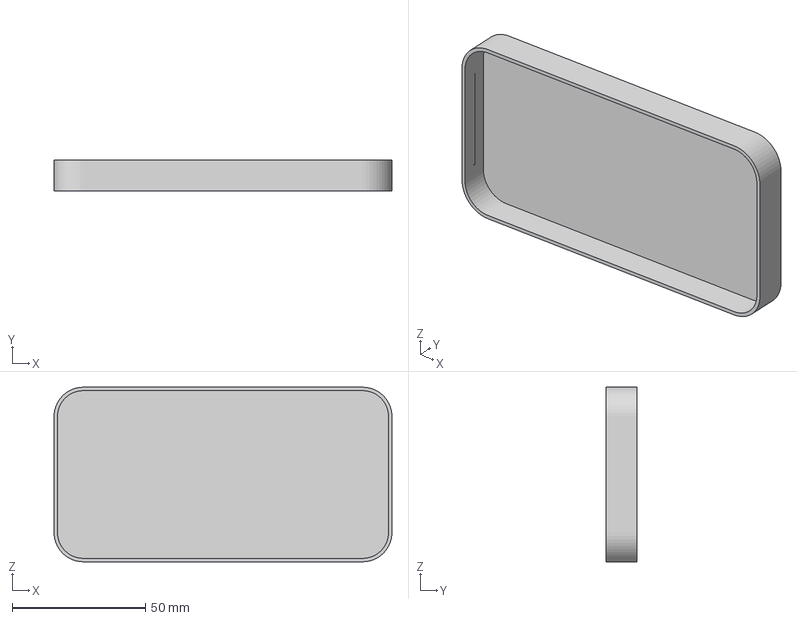
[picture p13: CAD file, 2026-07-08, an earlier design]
Old/pack-box-lid.3mf
127.0 x 11.5 x 65.6 mm

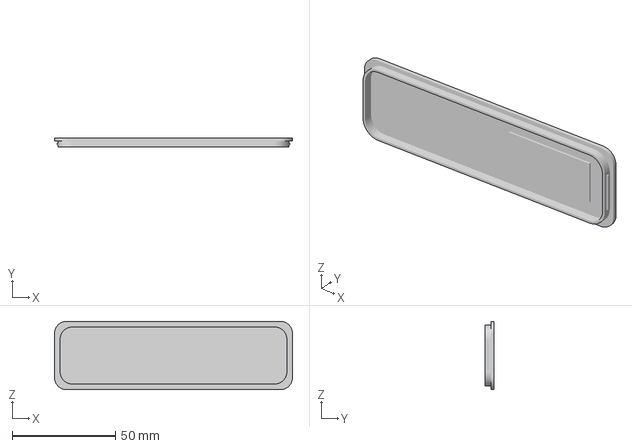
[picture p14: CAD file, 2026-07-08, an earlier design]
Old/transmitter-lid.3mf
115.0 x 4.50 x 33.0 mm

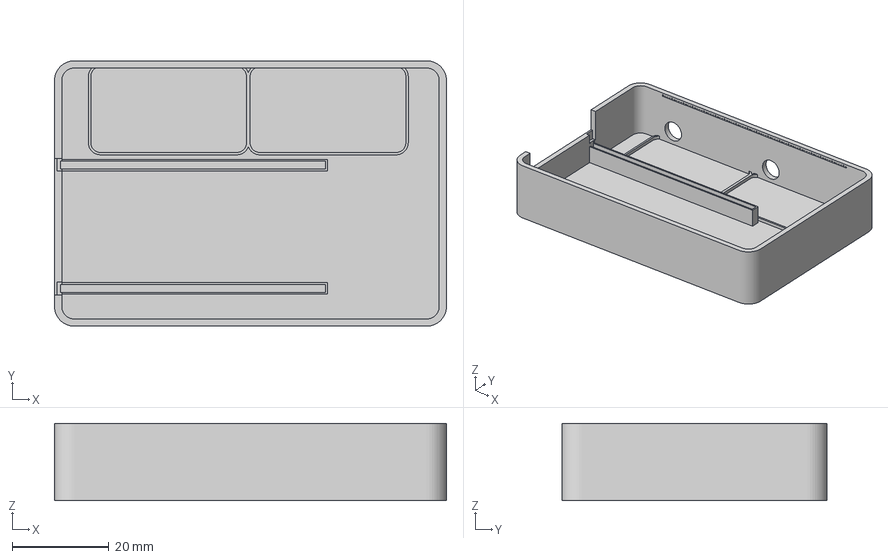
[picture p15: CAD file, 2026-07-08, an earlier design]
Old/Receiver-case.3mf
81.0 x 54.9 x 16.0 mm

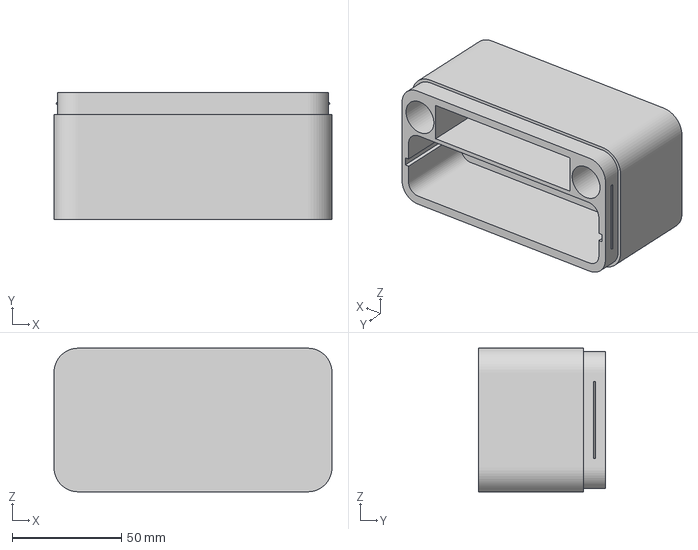
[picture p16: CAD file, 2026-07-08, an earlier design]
Old/pack-box.3mf
127.0 x 57.9 x 65.6 mm

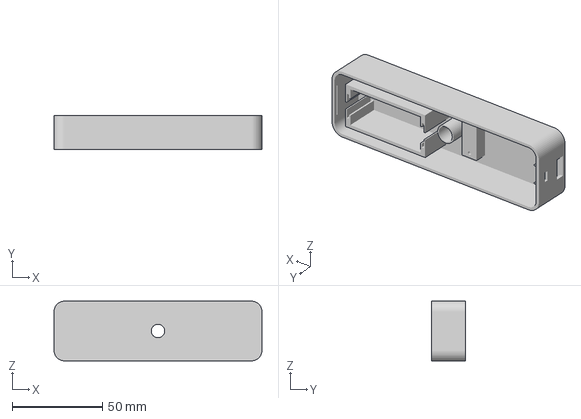
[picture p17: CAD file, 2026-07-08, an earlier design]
Old/transmitter-case.3mf
115.0 x 18.6 x 33.0 mm

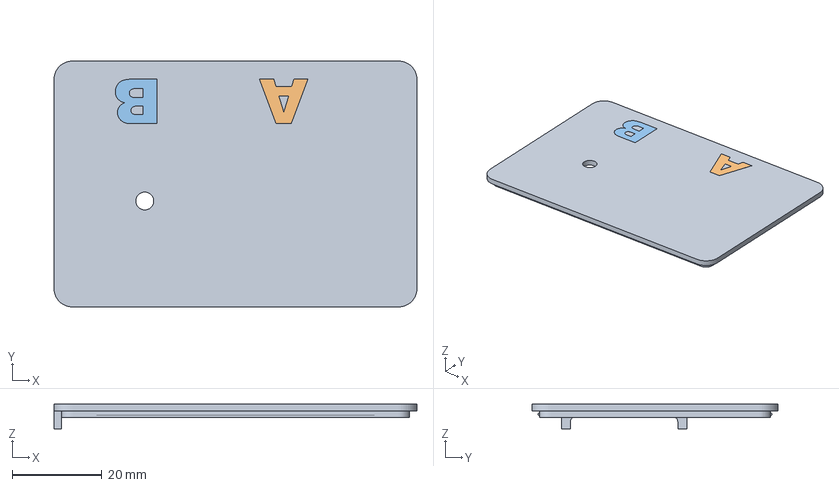
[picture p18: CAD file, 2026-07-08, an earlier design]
Old/receiver-lid.3mf
81.0 x 54.9 x 5.50 mm

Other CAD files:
Old/pack-box.f3d
Old/receiver.f3d
Old/transmitter.f3d

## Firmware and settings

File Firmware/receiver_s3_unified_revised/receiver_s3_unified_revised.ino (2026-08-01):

/*
  ESP32-S3 DVS RECEIVER - UNIFIED (Serato CV02 + Traktor) + SETTINGS PORTAL
  - Generates timecode for two decks in real time, speed and direction driven
    by each transmitter's RPM over ESP-NOW. The FORMAT is a runtime setting:
      Serato  = full CV02 timecode (position + carrier).
      Traktor = carrier only. Traktor tracks speed+direction in RELATIVE mode
                from the bare quadrature carrier; disable its timecode error
                messages and it works without the MK2 position bitstream. This
                avoids the end-zone/loop-wrap/drift problems of synthesizing
                the full MK2 signal.
  - Settings portal: long-press the settings button and the receiver raises a
    WiFi access point (SETTINGS_AP_SSID / SETTINGS_AP_PASS) with a phone-sized
    web page at http://192.168.4.1/ - output gain (live, watch the DJ
    software's scope while sliding), timecode format, LED brightness, pairing
    window length, re-pair action, per-deck link status. Values persist in
    NVS. Timecode keeps generating while the portal is up (the AP shares the
    ESP-NOW channel). Press again or 5 min idle to exit.
  - Onboard RGB LED: BLUE blink = pairing window open, RED = no transmitters,
    ORANGE = one, GREEN = both, PURPLE breathing = settings portal active.

  USB CDC also exposes the DVS Manager protocol. A Windows tray application can
  read live deck telemetry and edit the same NVS settings without enabling the
  WiFi access point. Human-readable debug lines remain available alongside the
  machine protocol and are ignored by the manager.

  Requires the Adafruit NeoPixel library.
*/

#include <WiFi.h>
#include <WebServer.h>
#include <DNSServer.h>
#include <Preferences.h>
#include <esp_now.h>
#include <esp_wifi.h>
#include <esp_mac.h>
#include <esp_err.h>
#include <driver/i2s.h>
#include <math.h>
#include <Adafruit_NeoPixel.h>

// newlib libm has sincosf (one call for both) but math.h only declares it
// under _GNU_SOURCE, so declare it ourselves.
extern "C" void sincosf(float x, float *s, float *c);

// ===== I2S DAC pins (one stereo PCM5102A per deck) ====================
#define DAC_A_BCK_PIN   2
#define DAC_A_LRCK_PIN  1
#define DAC_A_DATA_PIN  42
#define DAC_B_BCK_PIN   14
#define DAC_B_LRCK_PIN  13
#define DAC_B_DATA_PIN  12

// ===== Onboard status LED (DevKitC-1 N16R8 WS2812 = GPIO 48) ===========
#define LED_PIN 48
#define NUM_LEDS 1
#define LED_BRIGHTNESS 40
Adafruit_NeoPixel led(NUM_LEDS, LED_PIN, NEO_GRB + NEO_KHZ800);

// ===== Radio / protocol (must match the transmitter) ==================
#define ESPNOW_CHANNEL 11
#define PROTOCOL_VERSION 1
#define MSG_HELLO 1
#define MSG_WELCOME 2
#define MSG_DATA 3
#define MSG_PING 4
#define MSG_EVENT 5   // transmitter status relayed to our serial (its own
                      // USB is unreachable while it spins on battery)
#define MSG_BUTTONS 6 // dicer button state (unit 3)
#define MSG_COMMAND 7 // receiver -> puck (rpmCenti = command, gyroRaw = arg)
#define CMD_SPINCAL 1 // re-arm the puck's spin-cal; arg = target rpm x100
#define PING_INTERVAL_MS 500
#define DECK_TIMEOUT_MS 1000

// ===== Auto-pairing (receiver assigns decks by transmitter MAC) ========
// Power the receiver first: for PAIRING_WINDOW_MS an unknown puck may claim
// a free deck (first to arrive = deck 1, second = deck 2); the window closes
// early as soon as both decks are claimed. A puck already
// in the table (dropped and powered back on) reclaims its own deck at any
// time, window or not. Table is RAM-only: rebooting the receiver, or a long
// press on the re-pair button, clears it and reopens the window.
#define PAIRING_WINDOW_MS 60000UL
#define REPAIR_BTN_PIN 4           // white button 1, momentary to GND
#define REPAIR_HOLD_MS 1500        // hold duration for either mapped action

// ===== Dicer (unit 3) -> USB-MIDI [TEST] ==============================
// The dicer sends its full button state as MSG_BUTTONS; we diff states
// into MIDI note on/off on the S3's NATIVE USB port. Requires Tools >
// USB Mode: "USB-OTG (TinyUSB)" - in CDC/JTAG mode MIDI compiles out
// (with a warning) and everything else still works.
// Note = MIDI_BASE_NOTE + mode*6 + button, so every mode page is a
// distinct set of notes for MIDI-learn.
#define DICER_ID 3
#define USB_MIDI_ENABLE 0         // production: MIDI/dicer output disabled.
                                  // The experimental dicer unit lives in
                                  // Experimental/; set to 1 + build in USB-OTG
                                  // (TinyUSB) mode to re-enable dicer->MIDI.
#define MIDI_CHANNEL 1
#define MIDI_BASE_NOTE 36
#if USB_MIDI_ENABLE && defined(ARDUINO_USB_MODE) && ARDUINO_USB_MODE == 0
  #include "USB.h"
  #include "USBMIDI.h"
  #define USB_MIDI_ACTIVE 1
  USBMIDI MIDI;
#else
  #define USB_MIDI_ACTIVE 0
  #if USB_MIDI_ENABLE
    #warning "USB-MIDI disabled: set Tools > USB Mode to USB-OTG (TinyUSB)"
  #endif
#endif

#define LED_UPDATE_MS 50          // fast enough for clean low-batt blinking

// Low-battery indication: the receiver compares each puck's last reported
// battery voltage against gBattLowV (portal-adjustable) and flashes the
// status LED to identify the deck - 1 flash deck 1, 2 flashes deck 2,
// 3 flashes both. See serviceLed() / ledPulses().

// [TEST] Link-loss failover: if a puck goes silent mid-performance, keep
// generating timecode at its last STABLE rpm (one that held within
// +-FAILOVER_STABLE_BAND_RPM for FAILOVER_STABLE_MS) instead of stopping
// the deck. Scratching never becomes the held value; a stopped platter
// holds 0, so "stop platter, then switch the puck off" still ends clean.
// The LED still drops to orange/red so the fallback is visible.
#define FAILOVER_ENABLE 1
#define FAILOVER_STABLE_BAND_RPM 0.75f
#define FAILOVER_STABLE_MS 2000

// ===== Serial debug (optional; not used to carry timecode) ============
// Set DEBUG_SERIAL 0 to silence all prints. It only reports whether the
// firmware booted and whether packets are arriving.
#define DEBUG_SERIAL 1
#define DEBUG_BAUD 115200
#define DEBUG_PRINT_INTERVAL_MS 500

// ===== DVS Manager over USB CDC =======================================
// Machine-readable lines always begin "@DVS ". Incoming commands use a
// compact key=value format so the receiver needs no JSON parser/library;
// outgoing replies and telemetry are JSON for easy desktop parsing.
#define USB_MANAGER_ENABLE 1
#define USB_MANAGER_PROTOCOL_VERSION 1
#define USB_MANAGER_TELEMETRY_MS 250
#define USB_MANAGER_RX_MAX 320
#define RECEIVER_FIRMWARE_VERSION "1.2.6"

// ===== Audio =========================================================
#define SAMPLE_RATE 44100
#define DMA_BUF_LEN 32            // small buffers = low output latency
#define DMA_BUF_COUNT 4

// ===== Timecode response ==============================================
#define BASE_RPM 33.333f
#define DEADZONE_RPM 0.04f
// Backspin headroom, per format - the two carriers are an octave and a bit
// apart, so a single limit cannot suit both.
//   Serato CV02: 1 kHz carrier at 33 1/3, so 8x = 8 kHz. No bandwidth concern.
//   Traktor:     2.5 kHz carrier, so 8x would be 20 kHz - 91% of Nyquist at
//                44.1 kHz. The PCM5102A's reconstruction filter is flat only
//                to ~19.8 kHz and the decoding input has its own anti-alias
//                filter with the same shape, so the carrier gets attenuated
//                twice (plus phase smear at the band edge) exactly when it is
//                changing fastest - it can fall under Traktor's detection
//                threshold and drop tracking. 6x = 15 kHz sits comfortably
//                inside the flat passband of both filters.
// 6x is 200 rpm, well beyond a realistic hand backspin (~100-170 rpm), so the
// cap is unreachable in practice. Past it the reported speed saturates rather
// than tracking - a graceful degradation, unlike losing the signal entirely.
#define MAX_RPM_RATIO 8.0f            // Serato CV02
#define MAX_RPM_RATIO_TRAKTOR 6.0f    // Traktor carrier-only
#define RPM_SMOOTHING 0.80f
// PCM5102A full scale is ~2.1 V RMS - far above consumer line level, and a
// massive overload for phono inputs (which also apply RIAA EQ; never feed
// them without an attenuator). 0.30 lands near normal line level; tune so
// Serato's calibration scope shows a round ring comfortably inside the
// view, then re-run Estimate on the noise threshold.
#define OUTPUT_GAIN 0.30f
#define GAIN_MIN 0.05f
#define GAIN_MAX 0.60f
// Gain is stored PER FORMAT. Serato peaks at `gain` while Traktor's carrier
// rides higher (see traktorLevelForGain), so one shared number meant a ~5 dB
// jump every time the format was switched and a fresh trim against the DJ
// software's scope each time. The wire/UI surface is unchanged: gGain is
// always the ACTIVE format's gain, which is the single value the manager app
// and the web portal read and write.

// ===== CV02 generator (Serato/Bridge-compatible) ======================
#define CV02_RESOLUTION 1000        // position bits per second at 33 1/3 rpm
#define CV02_BITS 20
#define CV02_SEED 0x59017UL
#define CV02_TAPS 0x361e4UL
#define CV02_LENGTH 712000UL        // full record: ~11.9 min of groove
// Loop a short window from the MIDDLE of the record instead of playing all of
// it. At the record's run-out Serato sees end-of-record and drops to INTERNAL;
// a backspin past position 0 also wraps (mod) into that same end zone. Staying
// in a mid-record window keeps the absolute position clear of both the lead-in
// and the run-out. RELATIVE MODE ONLY - each wrap is a harmless needle-skip in
// REL; in ABS mode the deck would jump every CV02_LOOP_SECONDS. (The original
// firmware avoided this by accident: a uint32 phase wrapped at bit 65536,
// ~65 s, so it never reached the end zone.)
#define CV02_LOOP_SECONDS 300UL
#define CV02_LOOP_START_SECONDS 30UL          // skip past the lead-in
#define CV02_LOOP_BITS (CV02_LOOP_SECONDS * CV02_RESOLUTION)
#define CV02_LOOP_START_BITS (CV02_LOOP_START_SECONDS * CV02_RESOLUTION)
#define CV02_PACKED_BYTES ((CV02_LOOP_BITS + 7) / 8)

// ===== Traktor generator - CARRIER ONLY ==============================
// Traktor tracks speed and direction in RELATIVE mode from the bare
// quadrature carrier alone; it does NOT need the MK2 position bitstream.
// So we emit just the carrier (no LFSR, no bit table, no loop, no wrap,
// no drift). Traktor flags "no timecode" - disable its timecode/calibration
// error messages (as PHASE and similar wireless systems instruct) and it
// tracks fine. This sidesteps every position-signal problem the MK2
// synthesis had (end-zone INT, loop-wrap skip, bit/carrier lock drift).
#define TRAKTOR_CARRIER_HZ 2500.0f      // carrier cycles/s at 33 1/3 rpm
#define CARRIER_LEVEL 0.55f             // carrier amplitude (rides OUTPUT_GAIN)
#define TRAKTOR_MAX_LEVEL 0.98f         // prevent int16 wrap at high portal gain

// ===== Settings portal =================================================
#define SETTINGS_BTN_PIN 5         // second PCB button to GND (INPUT_PULLUP).
                                   // ADJUST to match your board wiring.
#define SETTINGS_AP_SSID "DVS-Settings"
#define SETTINGS_AP_PASS "dvssetup"          // WPA2 needs >= 8 chars
#define SETTINGS_IDLE_TIMEOUT_MS 300000UL    // auto-exit after 5 min unused

#define FORMAT_SERATO  0
#define FORMAT_TRAKTOR 1

// Persisted physical-button actions. Keep these numeric values stable because
// they are stored in NVS and exchanged with DVS Manager.
#define BUTTON_ACTION_AP        0
#define BUTTON_ACTION_SWAP      1
#define BUTTON_ACTION_PAIR      2
#define BUTTON_ACTION_SPINCAL   3
#define BUTTON_ACTION_DISABLED  4
#define BUTTON_ACTION_MAX       BUTTON_ACTION_DISABLED

typedef struct __attribute__((packed)) {
  uint8_t  msgType;
  uint8_t  version;
  uint8_t  deckId;
  int16_t  rpmCenti;
  int16_t  gyroRaw;
  uint32_t seq;
  uint32_t timestampMicros;
} dvs_packet;

typedef struct {
  bool     assigned;        // slot has an owner MAC (sticky for the session)
  bool     seen;
  int16_t  rpmCenti;
  uint32_t lastSeq;
  uint32_t lastSeenMillis;
  uint32_t lastPingMillis;
  // Link stats, accumulated per status-print interval, reset at each print:
  // DATA packets received, packets lost (seq gaps), RSSI sum + worst (dBm).
  uint16_t rxWindow;
  uint16_t lostWindow;
  int32_t  rssiSum;
  int8_t   rssiMin;         // 127 = nothing received this interval
  uint8_t  mac[6];          // owner MAC, set at assignment, matched thereafter
} deck_state;

typedef struct {
  uint8_t     deckId;
  i2s_port_t  port;
  int         bckPin, lrckPin, dataPin;
  const char *taskName;
  float       filteredRpm;
  int64_t     cv02Phase;         // CV02: 64-bit phase, clean reverse/backspin
  int64_t     carrierPhase;      // Traktor: 1.0 (<<32) = one carrier cycle
} audio_deck_state;

deck_state deckStates[2];
portMUX_TYPE stateMux = portMUX_INITIALIZER_UNLOCKED;

// Unknown pucks may claim a free deck only while now < this (absolute millis).
volatile uint32_t pairingWindowEndMs = 0;

// Signed deadline comparison is safe when millis() wraps (all deadlines here
// are far shorter than 2^31 ms).
static inline bool timePending(uint32_t now, uint32_t deadline) {
  return (int32_t)(deadline - now) > 0;
}

static inline bool macEq(const uint8_t *a, const uint8_t *b) {
  return memcmp(a, b, 6) == 0;
}

// One pending slot per device prevents simultaneous puck HELLO/EVENT packets
// from overwriting each other before loop() services them. Bits 0..2 map to
// deck 1, deck 2, and the optional dicer.
volatile uint8_t pendingWelcomeMask = 0;
uint8_t pendingWelcomeMac[3][6] = {};
volatile uint8_t pendingEventMask = 0;
uint8_t  pendingEventCode[3] = {};
uint32_t pendingEventValue[3] = {};

volatile bool     dicerSeen = false;
volatile uint16_t dicerMask = 0;
volatile uint8_t  dicerMode = 0;
uint16_t dicerPrevMask = 0;
uint8_t  dicerActiveNote[6] = { 0, 0, 0, 0, 0, 0 };

uint8_t cv02PackedBits[CV02_PACKED_BYTES];

// ===== Runtime settings (NVS-backed, editable via the portal) =========
// Written from loop()/web handlers, read by the audio tasks - single-word
// volatile reads/writes are atomic on Xtensa, no locking needed.
Preferences settingsPrefs;
volatile float   gGain      = OUTPUT_GAIN;      // ACTIVE format's output gain
// The per-format pair behind gGain. Only touched from loop()/web/manager
// context; the audio tasks read gGain alone, exactly as before.
float            gGainSerato  = OUTPUT_GAIN;
float            gGainTraktor = OUTPUT_GAIN;
volatile uint8_t gFormat    = FORMAT_SERATO;    // FORMAT_SERATO / FORMAT_TRAKTOR
uint8_t          gBright    = LED_BRIGHTNESS;   // LED brightness
uint32_t         gPairWinMs = PAIRING_WINDOW_MS;
// Platter base speed (33.333 or 45) - CALIBRATION REFERENCE ONLY: it tells
// the pucks which quartz speed to trust when the portal's calibrate button
// re-arms their spin-cal. It deliberately does NOT rebase the timecode
// ratio math: the receiver mimics real vinyl (platter at 45 -> 1.35x tone),
// and the DJ software's own 33/45 selector does the normalising. Rebasing
// here too would double-compensate.
volatile float   gBaseRpm   = 33.3333f;
// Low-battery LED threshold (volts), receiver-side + portal-adjustable. A
// deck flashes its low pattern when its last reported battery voltage is
// below this. (The puck reports voltage over MSG_EVENT.)
volatile float   gBattLowV  = 3.50f;
// Keep battery telemetry/events active but allow the operator to suppress the
// receiver's repeating low-battery LED pulse pattern.
bool             gLowBatteryLedAlert = true;
// Kept in the USB schema for compatibility with older Manager releases. AP
// availability is now controlled solely by assigning an AP action to a button.
bool             gApFallback = true;
uint8_t          gButton1Action = BUTTON_ACTION_PAIR; // white: open pairing
uint8_t          gButton2Action = BUTTON_ACTION_AP;   // black: settings AP

bool      settingsActive    = false;
uint32_t  settingsLastHitMs = 0;
WebServer settingsServer(80);
DNSServer settingsDns;

// Last per-deck link stats computed by debugPrintStatus, for /api/status
// (loss -1 = no packets that interval).
float webLoss[2] = { -1.0f, -1.0f };
int   webRssi[2] = { 0, 0 };

// Pending puck-command repeats: commands are unicast one-shots and the
// link runs 10-25% loss, so each command is sent 5x spaced 150 ms apart.
uint8_t  cmdRepeatsLeft[2] = { 0, 0 };
uint32_t cmdNextMs[2]      = { 0, 0 };
int16_t  cmdArgCenti[2]    = { 0, 0 };

// Last calibration-related event per deck, shown on the portal.
char webCalMsg[2][48] = { "", "" };

uint32_t lastLedMillis = 0;
uint32_t lastLedPacked = 0xFFFFFFFFUL;
float    deckBattV[2] = { 0.0f, 0.0f };   // last reported battery voltage/deck
uint32_t lastDebugPrintMillis = 0;
uint32_t lastManagerTelemetryMillis = 0;
char     managerRxLine[USB_MANAGER_RX_MAX];
uint16_t managerRxLength = 0;

// Failover state: written only by each deck's own audio task; read by
// loop() for logging (transient races there are harmless).
float    failStableRpm[2]   = { 0.0f, 0.0f };
float    failCandRpm[2]     = { 0.0f, 0.0f };
uint32_t failCandSinceMs[2] = { 0, 0 };
volatile bool failHolding[2] = { false, false };

audio_deck_state audioDecks[2] = {
  { 1, I2S_NUM_0, DAC_A_BCK_PIN, DAC_A_LRCK_PIN, DAC_A_DATA_PIN, "audioDeckA", 0.0f, 0 },
  { 2, I2S_NUM_1, DAC_B_BCK_PIN, DAC_B_LRCK_PIN, DAC_B_DATA_PIN, "audioDeckB", 0.0f, 0 }
};

// ===== USB serial: DVS Manager + optional human debug ================
// Brings up USB CDC for the manager even when human debug is disabled.
// It never carries timecode and is serviced only from loop().
void setupDebugSerial() {
#if DEBUG_SERIAL || USB_MANAGER_ENABLE
#if defined(ARDUINO_USB_CDC_ON_BOOT) && ARDUINO_USB_CDC_ON_BOOT
  // A complete two-deck status frame is larger than the native USB CDC
  // default TX ring (256 bytes). Without a larger ring, setTxTimeoutMs(0)
  // correctly avoids blocking the audio/radio loop but truncates every frame.
  // Allocate enough space for several complete manager frames before begin().
  Serial.setTxBufferSize(2048);
#endif
  Serial.begin(DEBUG_BAUD);
#if defined(ARDUINO_USB_CDC_ON_BOOT) && ARDUINO_USB_CDC_ON_BOOT
  // Never let writes stall loop() when a host is attached but not draining
  // the port (manager or serial monitor closed mid-session).
  Serial.setTxTimeoutMs(0);
#endif
  delay(1000);
#endif
#if DEBUG_SERIAL
  Serial.println();
  Serial.println("DVS unified receiver boot (Serato CV02 + Traktor carrier)");
  Serial.printf("Debug baud: %lu\n", (unsigned long)DEBUG_BAUD);
  Serial.printf("ESP-NOW channel: %u\n", ESPNOW_CHANNEL);
#endif
}

// Simple boot log line, guarded so it compiles out when DEBUG_SERIAL 0.
void debugBootLog(const char *message) {
#if DEBUG_SERIAL
  Serial.println(message);
#else
  (void)message;
#endif
}

// Arduino normally generates prototypes for .ino functions, but keeping the
// manager's later dependencies explicit also makes this file friendly to
// conventional C++ tooling.
void clearPairingsAndReopen();
bool swapDeckAssignments();
void saveSettings();
void applyGainAndFormat(float newGain, uint8_t newFormat);

#if USB_MANAGER_ENABLE
static void managerJsonEscape(const char *src, char *dst, size_t dstSize) {
  if (dstSize == 0) return;
  size_t out = 0;
  while (*src && out + 1 < dstSize) {
    unsigned char c = (unsigned char)*src++;
    if ((c == '"' || c == '\\') && out + 2 < dstSize) {
      dst[out++] = '\\';
      dst[out++] = (char)c;
    } else if (c >= 0x20) {
      dst[out++] = (char)c;
    }
  }
  dst[out] = '\0';
}

static void managerSendJson(const char *json) {
  Serial.print("@DVS ");
  Serial.println(json);
}

static void managerSendResponse(uint32_t id, bool ok, const char *message) {
  char escaped[96], json[180];
  managerJsonEscape(message, escaped, sizeof(escaped));
  snprintf(json, sizeof(json),
           "{\"type\":\"response\",\"id\":%lu,\"ok\":%s,\"message\":\"%s\"}",
           (unsigned long)id, ok ? "true" : "false", escaped);
  managerSendJson(json);
}

static void managerSendEvent(const char *name, uint8_t deck, const char *detail) {
  char escapedName[48], escapedDetail[96], json[230];
  managerJsonEscape(name, escapedName, sizeof(escapedName));
  managerJsonEscape(detail, escapedDetail, sizeof(escapedDetail));
  snprintf(json, sizeof(json),
           "{\"type\":\"event\",\"name\":\"%s\",\"deck\":%u,\"detail\":\"%s\",\"at\":%lu}",
           escapedName, (unsigned)deck, escapedDetail, (unsigned long)millis());
  managerSendJson(json);
}

static void managerSendHello(uint32_t id) {
  uint64_t chip = ESP.getEfuseMac();
  char json[240];
  snprintf(json, sizeof(json),
           "{\"type\":\"hello\",\"id\":%lu,\"protocol\":%u,"
           "\"firmware\":\"%s\",\"device\":\"DVS Receiver\","
           "\"serial\":\"%04X%08X\"}",
           (unsigned long)id, (unsigned)USB_MANAGER_PROTOCOL_VERSION,
           RECEIVER_FIRMWARE_VERSION, (unsigned)((chip >> 32) & 0xFFFF),
           (unsigned)(chip & 0xFFFFFFFFUL));
  managerSendJson(json);
}
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
void loop() {
  serviceManagerSerial();
  serviceReceiverButtons();
  serviceCommandRepeats();
  if (settingsActive) {
    settingsDns.processNextRequest();
    settingsServer.handleClient();
    if (millis() - settingsLastHitMs > SETTINGS_IDLE_TIMEOUT_MS)
      stopSettingsMode();             // nobody using it - drop the AP
  }
  serviceEspNowControl();
  serviceTransmitterEvents();
  serviceFailoverLog();
  serviceDicerMidi();
  if (millis() - lastLedMillis >= LED_UPDATE_MS) {
    lastLedMillis = millis();
    serviceLed();
  }
  debugPrintStatus();
  serviceManagerTelemetry();
  delay(1);
}

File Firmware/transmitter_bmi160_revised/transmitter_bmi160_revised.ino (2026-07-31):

/*
  ESP32-C3 DVS TRANSMITTER + BMI160/BMI120  [TEST]
  - Same firmware as the MPU6050 puck (battery monitor, EVT relay, boot
    diagnostics, handshake ACK counters, spin-cal learn-once) with the gyro
    driver swapped for a Bosch BMI160 or register-compatible BMI120.
  - Wiring per the transmitter schematic:
      BMI160 SDA -> GPIO8, SCL -> GPIO9, CS -> 3V3 (I2C mode),
      SAO -> GND (address 0x68). INT1 -> GPIO4 carries data-ready.
      Battery: BAT+ (after switch) -> 100k -> GPIO3 -> 100k -> GND, 100 nF.
      Battery feeds the C3's 5V/VIN pin (never 3V3).
  - IMU is mounted upside-down on the PCB, so the Z axis is inverted vs the
    MPU6050 puck. rawGyroToNominalRPM has no negation to compensate.
  - Reads platter rotation from the gyro Z axis, sends RPM ~500x/sec over
    ESP-NOW (broadcast). Auto-zeroes the gyro at boot (platter STOPPED).

  Serial at 115200 for boot/debug (any USB mode).
*/

#include <WiFi.h>
#include <esp_now.h>
#include <esp_wifi.h>
#include <Wire.h>
#include <Preferences.h>
#include <math.h>

// ===== Identity =======================================================
// The puck carries no deck number and no receiver MAC. It broadcasts, and
// the receiver auto-assigns a deck by this puck's (factory, stable) MAC:
// first puck to reach the receiver during its pairing window = deck 1,
// second = deck 2, and a puck that drops and returns reclaims its slot.
// Outgoing packets send deckId 0 ("unassigned"); the receiver ignores it
// and routes by MAC. The assigned deck comes back in WELCOME/PING, for
// serial display only.
#define DECK_ID 0

// ===== BMI160 / BMI120 (gyro) =========================================
#define SDA_PIN 8
#define SCL_PIN 9
#define INT1_PIN 4               // data-ready from the BMI160 (see DRDY below)
#define BMI160_ADDR 0x68         // SAO tied to GND (0x69 if tied high)

#define BMI160_REG_CHIP_ID    0x00
#define BMI160_CHIP_ID_VAL    0xD1
#define BMI120_CHIP_ID_VAL    0xD3
#define BMI160_REG_PMU_STATUS 0x03
#define BMI160_REG_GYR_Z_L    0x10   // Z low byte; BMI160 data is little-endian
#define BMI160_REG_STATUS     0x1B   // bit 6 = drdy_gyr
#define BMI160_STATUS_DRDY_GYR 0x40
#define BMI160_REG_GYR_CONF   0x42
#define BMI160_REG_GYR_RANGE  0x43
#define BMI160_REG_INT_EN1    0x51
#define BMI160_REG_INT_OUT_CTRL 0x53
#define BMI160_REG_INT_LATCH  0x54
#define BMI160_REG_INT_MAP1   0x56
#define BMI160_REG_CMD        0x7E
#define BMI160_CMD_SOFT_RESET 0xB6
#define BMI160_CMD_GYR_NORMAL 0x15   // gyro -> normal power mode

// ===== Data-ready sync (INT1) =========================================
// The gyro runs at 800 Hz while we send at 500 Hz. Reading on a free-running
// timer means each read lands anywhere inside the sensor's 1.25 ms update
// window, so the sample age jitters by up to a full ODR period. On a velocity
// signal that timing jitter IS velocity noise, and it is worst exactly during
// fast scratches (a 10 rpm/ms slew turns 1 ms of jitter into 10 rpm of error).
// Syncing the read to data-ready removes it.
//
// Bit positions below are taken from the BMI160 register map. Note that
// INT_MAP[1] puts INT1 in the HIGH nibble and INT2 in the low one, which is
// the opposite of the layout INT_OUT_CTRL uses - easy to get backwards.
//
//   INT_EN[1]     b7..b0: reserved | fwm_en | ffull_en | DRDY_EN | low_en |
//                         highg_z_en | highg_y_en | highg_x_en
//   INT_OUT_CTRL  b7..b0: int2_output_en | int2_od | int2_lvl | int2_edge |
//                         INT1_OUTPUT_EN | int1_od | INT1_LVL | int1_edge
//   INT_LATCH     b3..b0: int_latch (0 = non-latched)
//   INT_MAP[1]    b7..b0: INT1_DRDY | int1_fwm | int1_ffull | int1_pmu_trig |
//                         int2_drdy | int2_fwm | int2_ffull | int2_pmu_trig
//
// The bounded wait in waitGyroDataReady() still covers the case where the pin
// itself never arrives (broken/absent INT1 trace): the puck reverts to the
// previous free-running behaviour and reports EVT_DRDY_FALLBACK rather than
// stalling the 500 Hz stream.
#define BMI160_INT_EN1_DRDY   0x10   // INT_EN[1] bit 4 = int_drdy_en
#define BMI160_INT_OUT_INT1   0x0A   // INT1 output_en (b3) + active-high (b1),
                                     // push-pull (od=0), level-triggered
#define BMI160_INT_LATCH_NONE 0x00   // non-latched; pulses on each new sample
#define BMI160_INT_MAP1_DRDY_INT1 0x80  // INT_MAP[1] bit 7 = int1_drdy
#define DRDY_WAIT_TIMEOUT_US  1500UL // > one 800 Hz ODR period, << the 2 ms slot
// Consecutive timeouts before giving up. Kept small deliberately: while we are
// still waiting-and-timing-out the send rate sags (each slot pays the timeout),
// so a board where INT1 does not work should bail out in ~100 ms rather than
// limp for half a second.
#define DRDY_FALLBACK_MISSES  50

// Gyro full-scale range + matching sensitivity (keep these consistent):
//   0x00=+-2000dps/16.384  0x01=+-1000dps/32.768  0x02=+-500dps/65.536
//   0x03=+-250dps/131.072  0x04=+-125dps/262.144
#define GYR_RANGE_SEL    0x01     // +-1000 dps => ~5x nominal backspin headroom
#define GYRO_LSB_PER_DPS 32.768f  // 2^15 / 1000
// GYR_CONF: bwp=normal(0b10 -> bits[5:4]), odr=800 Hz(0x0B -> bits[3:0]).
// 800 Hz ODR, normal-mode filter ~= 230 Hz 3 dB -> low control latency,
// comparable to the MPU6050's 188 Hz DLPF.
#define GYR_CONF_VAL     0x2B

// ===== Radio / protocol ==============================================
#define ESPNOW_CHANNEL 11
#define SEND_RATE_HZ 500
#define SEND_INTERVAL_US (1000000UL / SEND_RATE_HZ)
#define HANDSHAKE_INTERVAL_MS 250
#define HANDSHAKE_TIMEOUT_MS 2000
#define USE_BROADCAST 1           // broadcast DATA = no ACK/retry = low jitter
// Default ESP-NOW rate is 1 Mbps 802.11b: ~650 us airtime per packet, i.e.
// ~33% channel use per deck at 500 Hz (two decks collide a lot). Legacy
// OFDM 6 Mbps still cuts airtime ~3x but decodes ~15 dB weaker signals
// than the 24 Mbps used before - much better range; 24M was dropping ~40%
// of packets across a room. Only affects our TX side; any ESP32 receives
// it fine. Set to 0 to fall back to the stock rate.
#define ESPNOW_FAST_RATE 1
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

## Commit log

2026-07-08 Wireless Gyro DVS — firmware, cases, web flasher
    DIY digital vinyl system with no needle and no timecode record: a
    battery-powered gyro puck streams platter RPM over ESP-NOW to an ESP32-S3
    receiver that generates timecode compatible with Serato CV02 or Traktor
    Scratch MK2 into dual I2S DACs. One receiver drives two decks.
    Lineage: based on FelipeAlme/DVS-Wireless-DIY-DJ-System by Felipe Alme,
    who started this project. Reworked with precision/latency fixes,
    self-learning gyro calibration, and a fast ESP-NOW rate.
    [Receiver-case.3mf, pack-box-lid.3mf, pack-box.3mf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]
2026-07-08 Fold web flasher into main/docs (one branch, GitHub Pages from /docs)
    Moves the ESP Web Tools flasher + firmware bins from the gh-pages branch
    into docs/ on main, so it's versioned alongside the firmware and needs no
    worktree juggling. Repoint GitHub Pages to main /docs; gh-pages can then
    be removed. Adds .nojekyll and tightens .gitignore (build/, KiCad WIP).
2026-07-17 Serato receiver: revert 64-bit phase + small DMA buffers to fix random INT drops
    Serato would randomly fall back to internal mode. Suspected cause:
    halved DMA cushion (32-frame buffers) plus per-sample 64-bit modulo
    math risking momentary underruns, which Serato treats as signal loss.
    - DMA_BUF_LEN back to 64 (~5.8 ms cushion, as upstream)
    - cv02Phase back to uint32 with 16 fractional bits (upstream scheme);
    drops the per-sample 64-bit modulos and per-buffer phase fold
    - Keeps the RPM deadzone fix, 8x speed clamp, and per-buffer rounded
    phase step
    Also updates the web flasher binary (docs/firmware/receiver-serato-s3.bin)
    to this build.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
2026-07-18 @ Restructure firmware repo; MIDI-free production binaries; fix output gain
    Sync repo to the reorganized firmware layout and rebuild the web-flasher
    binaries with arduino-cli (esp32 core 3.3.10).
    Firmware:
    - Serato receiver is now receiver_s3_cv02 (battery LED, link failover);
    old receiver_s3 archived under old/.
    - Transmitter is now transmitter_c3_mpu6050; old transmitter_c3 archived.
    - Add transmitter_bmi160 and transmitter_s3_display variants.
    - Both receivers: USB_MIDI_ENABLE 0 (dicer->MIDI is experimental, kept out
    of production builds; re-enable with USB-OTG/TinyUSB).
    - Serato OUTPUT_GAIN 0.70 -> 0.30: line level, not phono. Overdriving an
    input (esp. phono, with RIAA EQ) clippe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
2026-07-19 @ Auto-pair transmitters to decks by MAC (no per-puck deck/receiver-MAC config)
    The puck no longer carries a deck number or the receiver MAC - it broadcasts,
    and the receiver owns a 2-slot MAC->deck table (RAM-only):
    - Unknown puck: claims a free deck (first=1, second=2) only during a 60 s
    pairing window that opens at receiver boot.
    - Known puck (dropped, powered back on): reclaims its own deck any time,
    window or not - so a battery swap mid-set returns to the same deck.
    - Route DATA by source MAC; packet deckId is ignored (pucks send 0).
    - WELCOME/PING carry the assigned deck for the puck to display.
    - Re-pair: long-press a button on GPIO4 clears the table and reopens the
    window (or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
2026-07-19 @ Auto-pair: port transmitter_bmi160 to the MAC-based scheme too
    Same change as transmitter_c3_mpu6050: broadcast HELLO/DATA/EVENT, drop
    DECK_ID and the hardcoded receiverMAC, accept WELCOME/PING addressed to us
    regardless of deck number. This is the puck andy currently uses.
    transmitter_s3_display stays on the old protocol (future/experimental).
    @
2026-07-19 @ Perf/battery polish: sincosf, non-blocking debug serial, TX idle sleep
    Receivers (CV02 + Traktor):
    - sinf+cosf -> single sincosf call per sample (~40% cheaper transcendentals
    in the render loop).
    - Serial.setTxTimeoutMs(0) on CDC builds so debug prints can never stall
    loop() when a USB host is attached but not reading the port.
    - CV02 lfsrBit via __builtin_parity (boot-time, consistency with Traktor);
    fix stale "512 KB in PSRAM" comment (~37.5 KB at the 300 s loop).
    Transmitters (both pucks):
    - Idle the CPU (delay(1) -> FreeRTOS WFI) between 2 ms send slots instead
    of busy-spinning, only when >1.2 ms remains so send timing is unaffected.
    Saves battery on a device that lives on b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
2026-07-19 @ Auto-pair: close the pairing window as soon as both decks are claimed
    The LED kept its pairing blink for the full 60 s window even after both
    pucks had paired. Closing the window at the second assignment makes the
    LED go solid green immediately and stops any third unit from claiming a
    slot after the rig is complete.
    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
2026-07-19 @ Radio range: ESP-NOW rate 24M -> 6M OFDM, pin TX power to max
    At 24 Mbps the link was dropping ~40% of packets across a room (rx vs seq
    delta in the debug log); 6 Mbps decodes ~15 dB weaker signals while still
    cutting airtime ~3x vs the 1 Mbps default. Both pucks changed.
    Also pin esp_wifi_set_max_tx_power(84) on pucks AND receivers - the
    WELCOME/PING replies travel the same marginal path back to the puck.
    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
2026-07-19 Receivers: loss% + RSSI link stats in serial; pucks: TX power down to 8.5 dBm
    Status line now prints what RF tuning actually needs:
    D1 ON rpm=33.33 loss= 1.2% rssi=-58/-66 age=2ms ...
    - loss = share of the puck's packets lost this 500 ms interval (seq gaps
    accumulated per interval; a puck reboot / seq reset is detected and not
    counted as loss)
    - rssi = interval average / worst, in dBm, from the radio's own meter
    Drops seq/rx (internal counters), lost (only showed the last packet's gap)
    and heap (steady for weeks - was a leak check).
    Pucks: esp_wifi_set_max_tx_power 84 -> 34 (8.5 dBm). Small-antenna C3
    boards are known to get less reliable at max power (PA overdrives the
    mismatched a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
2026-07-19 @ Pucks: TX power back to max (84) - bench tests showed it is best
    Swept 8.5 / 15 / 20 dBm at range with the new loss/rssi stats: both RSSI
    and packet loss improved monotonically with power. The small-antenna
    "overdrive gets worse at max" hypothesis did not hold on these boards.
    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
2026-07-19 Release: channel 11, refreshed flasher binaries + auto-pair instructions
    - ESPNOW_CHANNEL back to 11 across all four sketches (6 was only a bench
    experiment; 11 is the shipping default).
    - Rebuild all web-flasher binaries with everything on this branch:
    auto-pairing, loss%/RSSI serial stats, CV02 mid-record loop window
    (Serato INT fix), 0.30 output gain, 6M PHY + max TX power, perf/battery
    polish. Manifests bumped to 1.1.0.
    - Flasher gains a BMI160 transmitter target (transmitter-c3-bmi160.bin +
    manifest) alongside the MPU6050 puck; both are config-free now.
    - Flasher page + receiver boot print updated for auto-pairing (no more
    Deck ID / receiver MAC instructions).
    Co-Authored-B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
2026-07-19 README: update to match shipped auto-pair + Serato-INT fix + BMI160 puck
    - Drop stale references to Deck ID edits and receiverMAC paste; document
    the new power-order pairing ritual, GPIO4 re-pair button, RAM-only
    MAC table, and same-binary-flashes-every-puck behavior.
    - Add BMI160 puck alongside the MPU6050 variant in the layout table and
    quick-start; both sketches ship in the flasher.
    - Explain the new receiver serial fields (loss%, rssi avg/worst) and the
    BLUE-blinking pairing LED state.
    - Note the CV02 mid-record loop window (Serato INT fix) alongside
    Traktor's existing one; call out line inputs (not phono) prominently.
    - Refresh troubleshooting for the shipped stats; reflect th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
2026-07-31 Replace project with complete firmware and DVS Manager release
    [Receiver-case.3mf, pack-box-lid.3mf, pack-box.3mf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]
2026-07-31 Restore legacy firmware for non-custom PCB builds
2026-07-31 Replace legacy firmware folder with original CAD build files
    [Receiver-case.3mf, pack-box-lid.3mf, pack-box.3mf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]
2026-07-31 Add low-battery LED control and improve window dragging
2026-08-01 Add configurable receiver buttons and manager close behavior
2026-08-01 Simplify receiver AP button settings
2026-08-02 Add printable cases and PCB manufacturing files
    [RX-bottom.stl, RX-button.stl, RX-top.3mf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]
2026-08-02 Document enclosure BOM and schematics
2026-08-02 Correct enclosure mounting hardware
2026-08-02 Add assembled enclosure previews
